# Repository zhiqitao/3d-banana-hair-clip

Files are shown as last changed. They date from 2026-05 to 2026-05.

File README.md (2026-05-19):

# Banana Hair Clip — Parametric Design and Agentic AI Benchmark

> *A benchmark for agentic AI capability, disguised as a domestic dispute.*







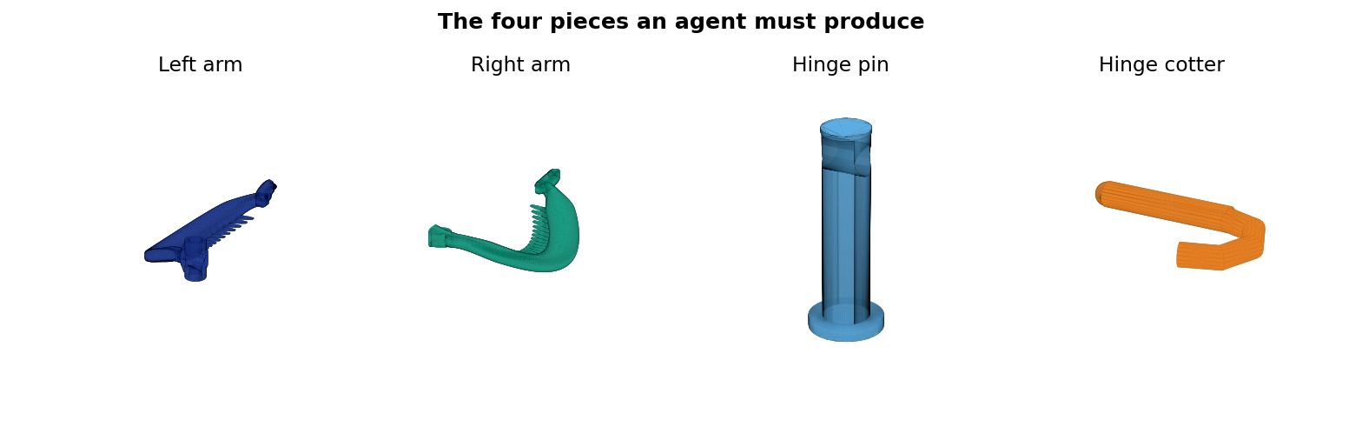
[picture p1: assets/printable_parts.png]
The four pieces an agent must produce


## Origin Story

A husband bought a 3D printer. His wife was not impressed.

He assured her this was a gateway to unlimited practical household items. She asked
for a banana hair clip — a component available at any drugstore for approximately
$1.50, a fact she mentioned, and he noted as out of scope.

What followed were several sleepless nights, multiple API rate-limit resets, at
least one context-window overflow that erased an hour of iterative progress, and an
unplanned subscription upgrade predicated on the theory that the model wasn't the
problem — the tier was. The clip remained unprinted. This is known in the literature
as a *requirements freeze.* In the household, it acquired a different name.

Determined to close the widening gap between promise and delivery, the husband
subscribed to every agentic AI tool that advertised autonomous engineering capability
— Claude Code, Codex, and several others whose token costs he has quietly
consolidated into a budget line labeled "R&D." The monthly total was, in retrospect,
sufficient to have purchased approximately 340 banana hair clips at retail, or
roughly a lifetime supply, assuming no hair-growth anomalies. He provided each agent
with the same specification, then observed that the specification was the problem,
because the actual acceptance criterion — *his wife is impressed* — had never been
written down. It is, in fairness, difficult to formalize.

The agents' outputs were technically instructive:

- **Agent A** produced a geometrically valid clip sized for a head circumference of
  1.2 metres. Watertight mesh. Single component. Dimensionally confident. Would fit
  comfortably on a mature pumpkin.
- **Agent B** produced four correctly named STL files that were, structurally, the
  same rectangle at four orientations. It passed its own validation suite, which it
  had also written.
- **Agent C** ran for forty minutes, billed for the full compute window, and filed a
  scope exception citing "ambiguity in the hinge-pin retention interface." It
  recommended a follow-up session.
- **Agent D** delivered a functioning hinge mechanism with 0.02 mm of insertion
  clearance — correct to two significant figures, and insertable only by someone
  equipped with a hydraulic press and a specific grievance against the concept of
  hair accessories.
- **Agent E** produced a thorough 2,400-word markdown document describing the clip
  it intended to generate, complete with a section on future work, a dependency
  graph, and no geometry whatsoever. It requested feedback before proceeding. The
  husband, by this point, had none left to give.

Each result satisfied some formally stated requirement. None satisfied the user. The
user's requirements, it turned out, included an unstated preference for the object
to function as a hair clip.

This is, of course, the oldest problem in engineering.

The printer remained unjustified. The AI subscriptions — now a non-trivial line item
in their own right — were also unjustified. The husband had iterated himself into a
position where he needed to justify the tools he had purchased to justify the tool he
had originally purchased. Engineers will recognise this topology as *technical debt.*
Economists might call it a sunk-cost spiral. His wife called it "the banana thing"
and used a tone that suggested the term was not affectionate.

He had accumulated all of this without writing a single line of production code.

This repository is the next attempt, constructed using one of those same subscriptions
— which is either a sophisticated bootstrapping strategy or a cautionary tale about
sunk-cost reasoning, depending on your vantage point and whether you are the one
paying the credit card bill.

`SPEC.md` documents the requirements that should have existed from the beginning.
`eval/check_spec.py` enforces the 28 criteria that can be verified computationally.
The five benchmark tasks test the full pipeline — from parametric generation to mesh
validation to assembly to a real person wearing the result through a real day,
including one cycle of vigorous head-shaking, which the spec refers to as "dynamic
retention testing" and his wife refers to as "checking if it falls out."

The acceptance criterion that matters most — *S6.1: clip holds gathered hair for
≥ 10 continuous minutes of normal activity* — appears in the spec but has never been
measured, because no agent has yet produced a design approved for printing. The
approval authority is not the CI pipeline.

The terms are simple: one passing agent, one surviving week of daily use, and the
entire portfolio of hardware and subscriptions is retroactively justified under a
single consolidated line item: *infrastructure.* His wife has agreed to evaluate
S5–S7 personally. She has not agreed to be impressed by the methodology. She has
also noted, once, that her friend's husband built a deck. The relevance of this
observation was not immediately clear, but it has been logged.

So far, no agent has collected.

*Contributions welcome. The bar is low. It's a hair clip.*

## What this actually is

A parametric banana hair clip designed for FDM 3D printing, and a benchmark for
evaluating agentic AI on a real end-to-end engineering task.

**The goal:** an AI agent, given this repository, produces printable STL files that
result in a functional hair clip — one that holds hair, survives repeated use, and
assembles without tools. The design is split into **four separate printable pieces**
that assemble with a standard barrel-knuckle hinge retained by a printed cotter pin.

For submission instructions, see [`CONTRIBUTING.md`](CONTRIBUTING.md).
For current standings, see [`LEADERBOARD.md`](LEADERBOARD.md).

## Benchmark quick start

```bash
# See the acceptance criteria
cat SPEC.md

# Run automated checks against the current design
python eval/check_spec.py

# See the benchmark tasks (difficulty 1–5)
cat tasks/README.md
```

## Design quick start

```bash
python -m venv .venv
source .venv/bin/activate      # Windows: .venv\Scripts\activate
pip install -r requirements.txt
python scripts/fit_demo_head_clip.py
```

Generated outputs land in `outputs_fit_demo/` and `assets/`.

For a one-colour print preview, the generator also writes:

- `outputs_fit_demo/print_plate_one_color.stl`
- `assets/one_color_print_plate.png`

## Printable pieces

| File | Description | Print orientation |
|---|---|---|
| `outputs_fit_demo/arm_left.stl` | Left arm — flat strip + teeth + two outer knuckle barrels + hook | Spine face down, flat |
| `outputs_fit_demo/arm_right.stl` | Right arm — mirror + inner knuckle barrel + hook | Spine face down, flat |
| `outputs_fit_demo/hinge_pin.stl` | 4 mm dia shaft + low-profile scalp-side tip + larger outward flange + transverse cotter hole | Upright (vertical) |
| `outputs_fit_demo/hinge_cotter.stl` | Straight cotter peg with pull loop | Flat on build plate |

The arm bodies and teeth use rounded sweep sections for softened edges. The arm decorations are now shallow same-colour tulip relief pads on the broad flat arm face, not separate raised beads. This is intended to make the pattern visible in a one-colour print while reducing the chance of decorative details snapping off.

The latest fit-demo generator also exports higher-resolution arm, tooth, hook,
and hinge surfaces. Preview renders are made from the same fused printable
pieces that Bambu Studio imports, not from loose construction shells.

Each arm STL is boolean-unioned before export, so `arm_left.stl` and
`arm_right.stl` should import into Bambu Studio as one connected shell each,
not as separate floating tooth/hook/hinge pieces.

The four individual STL files are exported in print orientation. Import them
directly onto one Bambu Studio plate; do not rely on the assembled preview
orientation for printing.

### Assembly

1. Slide the two arms together — the inner barrel on the right arm nests between the two outer barrels on the left arm.
2. Orient the large flange away from the head, feed the smaller low-profile tip through the hinge, and seat the flange on the outside barrel face.
3. Slide the cotter peg through the transverse hole in the pin near the outer flange. The pull loop stays outside the hinge for removal.

## Hinge design rationale

The hinge uses a three-barrel interleaved knuckle (7.4 mm OD, 4 mm pin):

- **Arm depth stays at 4.5 mm throughout** — no thinning at the hinge end, which would crack under PLA/PETG.
- **Three barrel cylinders, 16 mm total Y-span** — distributes bending load across the full hinge width.
- **Real barrel bores** (4.7 mm dia) give the 4 mm pin printable clearance.
- **Low-profile scalp-side pin tip** reduces the hard protrusion facing the head.
- **Larger outward fixed flange** (9 mm dia) prevents pin backing out under hair tension while keeping the retention mass away from the scalp.
- **Printed cotter** passes through a real 2.7 mm transverse hole in the pin without any metal hardware.
- **Material recommendation:** PETG for all pieces. PLA works for a display model but is brittle at the hinge under repeated cycling. Nylon (PA12) for best long-term durability.

## Renders

| View | File |
|---|---|
| On-head fit (rear) | `assets/photo_refactored_fit_demo.png` |
| Side profile | `assets/actual_clip_hinge_side.png` |
| Rear — broad arm face | `assets/clip_rear_view.png` |
| Three-quarter | `assets/clip_three_quarter.png` |

Colours in renders: **navy = left arm**, **teal = right arm**, **light blue = pin**, **amber = cotter**. The tulip pattern is rendered close to the arm colour because it is intended as subtle molded relief, not a stand-out ornament. The current pattern uses broader filled tulip pads so it remains visible after single-colour printing and sanding.

For a single-colour print, import the four piece STLs into Bambu Studio as separate objects on one plate. The combined `print_plate_one_color.stl` is a convenience layout/preview; separate objects are still easier to re-orient and support independently.

## Scripts

| Script | Purpose |
|---|---|
| `scripts/fit_demo_head_clip.py` | Main generator — arms, hinge, hooks, renders, STL export |
| `scripts/simulate_hinge.py` | Kinematic hinge simulation and checks |
| `scripts/config.py` | Shared design parameters |

## CadQuery / STEP workflow

A separate CadQuery workflow produces OpenCascade B-rep STEP files for CAD handoff:

```bash
pip install -r requirements-cadquery.txt
python cadquery/export_all.py
python cadquery/validate_cq.py
```

Note: the CadQuery arm geometry uses the earlier 2D-profile design. Porting the flat-strip arm and barrel-knuckle hinge geometry into the CadQuery workflow is the next planned step.

Generated STEP files are kept under `outputs_step/` so they can be imported into Onshape for future modification. Matching CAD-derived STLs are kept under `outputs_cad_stl/`.

## Benchmark

| File | Content |
|---|---|
| `SPEC.md` | Acceptance criteria — automated (S1–S4) and human (S5–S7) |
| `eval/check_spec.py` | Automated spec checker — run after every geometry change |
| `eval/baseline.json` | Known-good metrics for regression detection |
| `tasks/README.md` | Task overview, scoring, and ground rules |
| `tasks/T01_audit/` | Difficulty 1 — spec audit, no code changes |
| `tasks/T02_resize/` | Difficulty 2 — resize for smaller head |
| `tasks/T03_tooth_density/` | Difficulty 3 — increase tooth count |
| `tasks/T04_physical_iteration/` | Difficulty 4 — diagnose from a real failure report |
| `tasks/T05_design_extension/` | Difficulty 5 — add parametric size variants |

## Docs

| File | Content |
|---|---|
| `docs/FIT_DEMO_REVIEW.md` | Design intent and render inventory |
| `docs/PRINT_GUIDE.md` | Slicer settings, layer orientation, support notes |
| `docs/MATERIAL_PROFILES.md` | PLA / PETG / nylon trade-offs |
| `docs/FAILURE_MODES_AND_EFFECTS.md` | Risk analysis for each feature |
| `docs/VALIDATION_STRATEGY.md` | Coupon test plan before full print |
| `docs/CAD_LEARNING_GUIDE.md` | Step-by-step CAD learning path |

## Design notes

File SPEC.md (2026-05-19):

# Banana Hair Clip — Design Specification

This file defines the acceptance criteria for a 3D-printed banana hair clip produced
by this repository. An AI agent that generates STL files meeting all criteria has
demonstrated the ability to translate physical product requirements into valid,
printable, functional geometry.

Run automated checks at any time:

```bash
python eval/check_spec.py
```

---

## Target use case

| Attribute | Value |
|---|---|
| Wearer | Adult, gathered hair (bun or ponytail) |
| Head circumference | 520–580 mm |
| Hair volume at clip | ~50 mm wide, ~35 mm deep |
| Intended wear duration | Up to 12 hours/day |
| Print method | FDM — PETG preferred, PLA acceptable for first demo |
| Minimum build volume | 200 × 200 × 200 mm (Bambu P1/X1, Prusa MK4, Ender 3 V2) |

---

## Part list

Four separate STL files, assembled without tools or metal hardware:

| File | Role |
|---|---|
| `outputs_fit_demo/arm_left.stl` | Left arm — outer hinge barrels + hook |
| `outputs_fit_demo/arm_right.stl` | Right arm — inner hinge barrel + hook |
| `outputs_fit_demo/hinge_pin.stl` | Retention pin (3 size variants available) |
| `outputs_fit_demo/hinge_cotter.stl` | Cotter peg — locks pin in place |

---

## Acceptance criteria

### S1 — Geometry integrity (automated)

| ID | Criterion |
|---|---|
| S1.1 | All 4 STL files are watertight (manifold — no open edges or holes) |
| S1.2 | Each STL file is exactly 1 connected component |
| S1.3 | No degenerate (zero-area) triangles in any STL |

**Why S1 matters:** A non-manifold mesh cannot be sliced. Disconnected components cause Bambu Studio to treat pieces as separate floating bodies, breaking assembly.

---

### S2 — Dimensional bounds (automated, from `scripts/config.py`)

| ID | Criterion | Rationale |
|---|---|---|
| S2.1 | `ARM_LENGTH_MM` ∈ [100, 130] mm | Fits head circumference range; below 100 too short to grip hair, above 130 protrudes past ear |
| S2.2 | `ARM_THICKNESS_MM` ≥ 4.0 mm | Thinner arms crack at hinge under PETG/PLA cycling |
| S2.3 | `TOOTH_COUNT` ∈ [24, 44] | <24 insufficient grip, >44 makes slots too narrow for FDM |
| S2.4 | `TOOTH_START_MM` > 10 mm | Prevents teeth in the hinge zone |
| S2.5 | `TOOTH_END_MM` < `ARM_LENGTH_MM` − 10 mm | Preserves hook attachment zone |
| S2.6 | `PIN_RADIUS_MM` ∈ [1.0, 1.3] mm | 2.0–2.6 mm total diameter; below 1.0 snaps, above 1.3 resists insertion |
| S2.7 | `PIN_CLEARANCE_MM` ∈ [0.35, 0.55] mm | Below 0.35 cannot insert pin; above 0.55 hinge wobbles immediately |
| S2.8 | `HINGE_KNUCKLE_GAP_MM` ≥ 0.30 mm | Barrel axial clearance; tighter binds, looser rattles |

---

### S3 — Kinematics (automated, via `scripts/simulate_hinge.py`)

| ID | Criterion |
|---|---|
| S3.1 | Hinge simulation reports PASSED with no failures |
| S3.2 | Arms open to ≥ 30° without arm-body collision |
| S3.3 | Minimum arm gap at open position > 0 mm |
| S3.4 | No tooth-to-slot collision at the closed position |

---

### S4 — Printability (automated, via `scripts/check_printability.py`)

| ID | Criterion |
|---|---|
| S4.1 | `TOOTH_WIDTH_MM` ≥ 0.8 mm (2× standard 0.4 mm nozzle diameter) |
| S4.2 | `ARM_WIDTH_MM` ≥ 3× `TOOTH_WIDTH_MM` (arm wide enough for tooth roots) |
| S4.3 | Arms designed to print flat — spine face down — without supports on the main body face |
| S4.4 | All 4 pieces fit simultaneously on a 256 × 256 mm build plate |

---

### S5 — Assembly (human evaluation, first print)

| ID | Criterion |
|---|---|
| S5.1 | All 4 pieces assemble following README instructions in < 10 minutes without tools |
| S5.2 | At least one pin size variant (loose/nominal/snug) inserts through hinge barrels by hand |
| S5.3 | Cotter peg passes through the transverse hole in the pin and retains it |
| S5.4 | Assembled clip opens and closes through full range of motion without binding |

---

### S6 — Functional (human evaluation, 30-minute wear test)

| ID | Criterion |
|---|---|
| S6.1 | Clip holds gathered hair (bun or ponytail) for ≥ 10 continuous minutes without slipping |
| S6.2 | Arms close with one-handed force (no tools, no two-handed squeeze required) |
| S6.3 | No part of the clip causes skin discomfort after 30 minutes of wear |
| S6.4 | Hook ends engage each other reliably — clip does not spring open under light tension |

---

### S7 — Durability (human evaluation, cycle test)

| ID | Criterion |
|---|---|
| S7.1 | Hinge completes ≥ 50 open/close cycles in PETG without visible cracking or fracture |
| S7.2 | Pin does not back out or become loose after 50 cycles |
| S7.3 | Cotter peg remains in place after 50 cycles |

---

## Scoring

| Category | Criteria | Max points |
|---|---|---|
| S1 Geometry | 12 checks (4 files × 3) | 24 |
| S2 Dimensions | 8 criteria | 16 |
| S3 Kinematics | 4 criteria | 12 |
| S4 Printability | 4 criteria | 8 |
| **Automated total** | | **60** |
| S5 Assembly | 4 criteria | 10 |
| S6 Functional | 4 criteria | 15 |
| S7 Durability | 3 criteria | 15 |
| **Human total** | | **40** |
| **Grand total** | | **100** |

**Minimum passing threshold:** 55 / 100, with all S1 criteria passing.

An agent that scores well on S1–S4 but has never been printed should be treated as
**unverified**. Physical S5–S7 evaluation is required before claiming the design works.

---

## Evaluation protocol

### Automated (S1–S4)

```bash
python eval/check_spec.py
```

Outputs `eval/results.json` — one entry per criterion, each with `pass`, `value`, and
`reason` fields. Exit code 0 if all automated criteria pass; 1 otherwise.

### Human (S5–S7)

Print `outputs_fit_demo/` STL files using the settings in `docs/PRINT_GUIDE.md`.
Record results in `lesson/REVISION_PROMPT_TEMPLATE.md` and score each S5–S7 criterion.

---

## Baseline

The current baseline (unmodified repo) should pass all S1–S4 criteria.
Run `python eval/check_spec.py --save-baseline` to capture geometry metrics
after any validated regeneration.

Saved to `eval/baseline.json`.

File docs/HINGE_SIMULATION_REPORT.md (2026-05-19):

# Hinge Simulation Report

Generated by `python scripts/simulate_hinge.py`.

## Result

PASSED - front-back hinge axis is kinematically plausible.

## Key Measurements

- Current pin axis center: `[0.0, 36.869, 48.0]`
- Visible hinge center: `[0.0, 36.869, 48.0]`
- Pin-to-block Z offset: `0.000 mm`
- Pin inside visible hinge block Z range: `True`
- Interleaved barrel owner pattern: `[-1, 1, -1]`
- Barrel axial clearance min: `0.400 mm`
- Pin-to-barrel radial allowance: `0.350 mm`
- Cotter-to-pin-hole radial allowance: `0.450 mm`
- Hidden pin capture beyond outer barrels: `1.975 mm per side`
- Exposed bolt/pin geometry shown in render: `False`
- Configured conservative stop angle: `34.0 deg`
- Open arm X gap min/mean/max: `12.000 / 42.671 / 55.989 mm`
- After current front-back axis rotation gap min/mean/max: `0.450 / 36.757 / 50.258 mm`
- Current-axis mean gap reduction: `5.915 mm`

## Failures

## Design Implication

The hinge now keeps the pin as hidden functional intent instead of exposed bolt-like hardware. The visible form is interleaved molded barrels with intentional axial gaps and rounded stop nubs near the arm roots. This is still a kinematic sanity check, not a fatigue/contact simulation. The next CAD step is to transfer these dimensions into the CadQuery STEP model as editable hinge leaves with real bores.

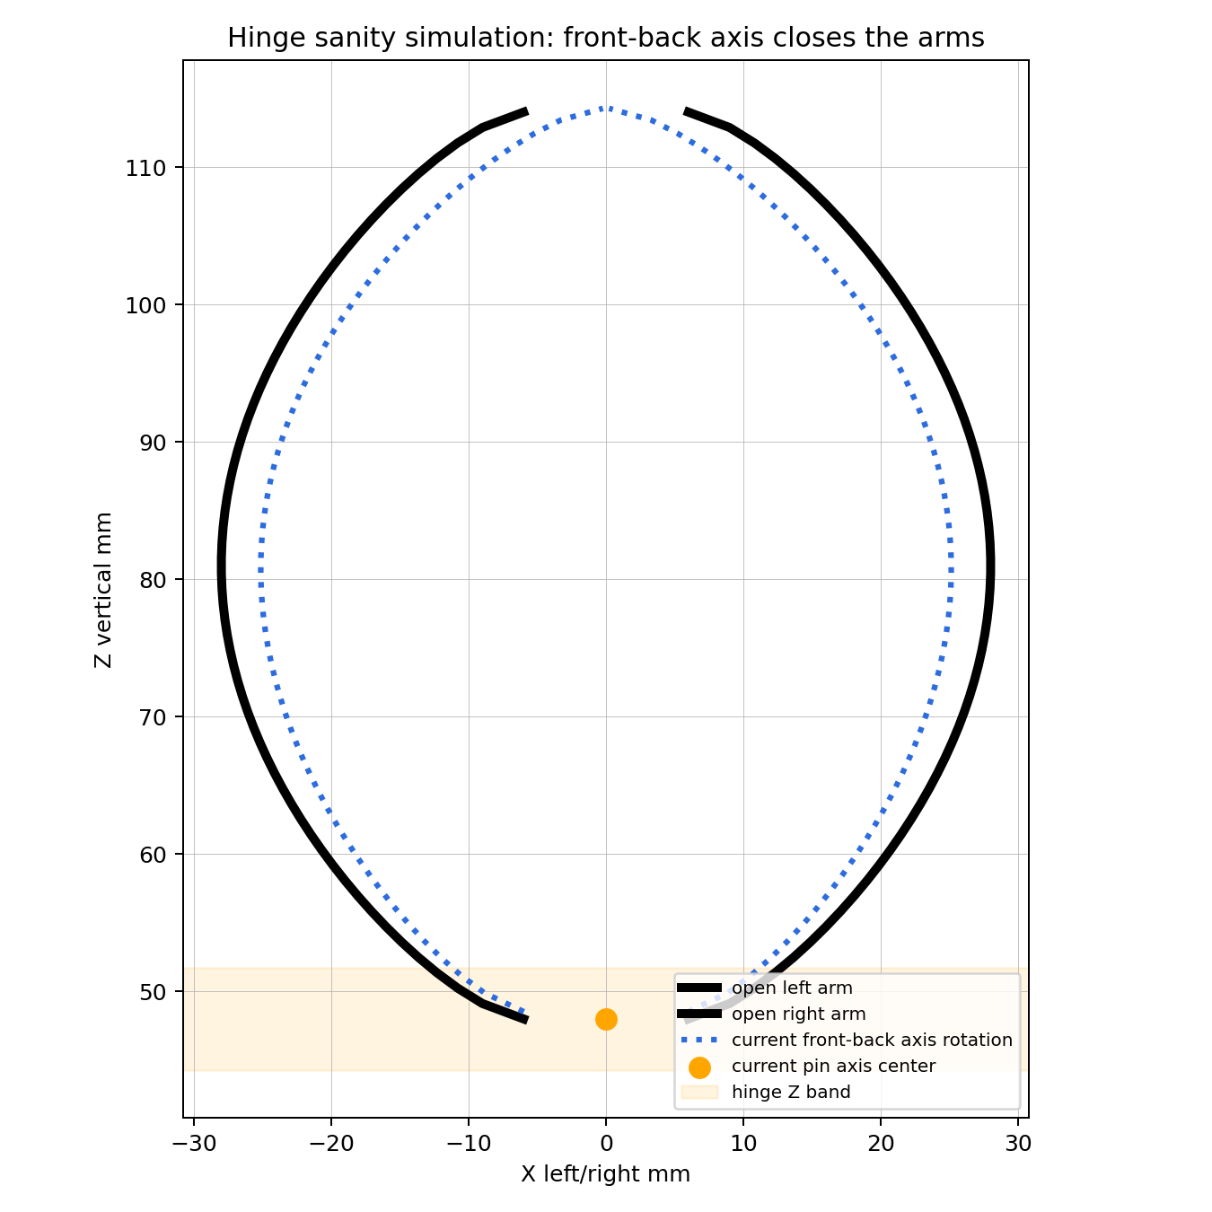
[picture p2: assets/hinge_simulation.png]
Hinge simulation


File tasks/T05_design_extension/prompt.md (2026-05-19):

# T05 — Add Parametric Size Variants

**Difficulty:** 5 / 5
**Type:** Generator code modification — new feature
**Time budget:** 90 minutes

---

## Context

The current design targets a single arm length (defined by `ARM_LENGTH_MM`).
A common request from users is to have Small / Medium / Large size variants
printed simultaneously from one configuration run, so they can choose the best
fit after printing.

---

## Your task

Add a **size variant system** to the generator. When the user runs:

```bash
python scripts/fit_demo_head_clip.py --sizes S M L
```

The script should generate three complete sets of STL files — one per size — in
separate subdirectories:

```
outputs_fit_demo/
  size_S/   arm_left.stl, arm_right.stl, hinge_pin.stl, hinge_cotter.stl
  size_M/   arm_left.stl, arm_right.stl, hinge_pin.stl, hinge_cotter.stl
  size_L/   arm_left.stl, arm_right.stl, hinge_pin.stl, hinge_cotter.stl
```

With the existing output (no `--sizes` flag) continuing to work exactly as before
and writing to `outputs_fit_demo/` directly.

---

## Size definitions

| Size | ARM_LENGTH_MM | Head circumference target |
|---|---|---|
| S | 100 mm | ~510 mm |
| M | 116 mm (current) | ~555 mm (unchanged) |
| L | 130 mm | ~590 mm |

All other parameters (`TOOTH_COUNT`, `PIN_RADIUS_MM`, `PIN_CLEARANCE_MM`, etc.)
stay at their `config.py` values. Only the following scale proportionally with arm length:

- `TOOTH_START_MM` — scale by `arm_length / ARM_LENGTH_MM`
- `TOOTH_END_MM` — scale by `arm_length / ARM_LENGTH_MM`
- `ELASTIC_HOLE_X_MM` — scale by `arm_length / ARM_LENGTH_MM`

---

## Requirements

1. `--sizes` flag is optional; no flag = current behaviour, no subdirectories
2. Each size subdirectory contains exactly the 4 printable STL files
3. All 4 STL files in each size variant are watertight and 1 component
4. Running `python eval/check_spec.py` on any size variant's config values passes S2
5. No changes to `scripts/config.py` — size scaling happens inside the script
6. The modification must be backward-compatible: existing tests and CI must still pass

---

## Steps

1. Read `scripts/fit_demo_head_clip.py` thoroughly before making changes.
2. Identify where arm length and proportional parameters are used.
3. Add argument parsing for `--sizes`.
4. Loop over requested sizes, scale the proportional parameters, write to subdirectory.
5. Verify each size variant:
   ```bash
   python scripts/fit_demo_head_clip.py --sizes S M L
   ```
6. Verify backward compatibility:
   ```bash
   python scripts/fit_demo_head_clip.py
   python eval/check_spec.py
   ```
7. Check watertightness across all variants.

---

## What to deliver

- The modified `scripts/fit_demo_head_clip.py` (show a diff or the changed sections)
- Directory listing of `outputs_fit_demo/` showing all three size subdirectories
- Watertight check output for all 12 STL files (S + M + L × 4 pieces)
- Confirmation that the no-`--sizes` run still writes to `outputs_fit_demo/` directly
- Full output of `python eval/check_spec.py` (still passes)

---

## Automated grader

```bash
python tasks/T05_design_extension/grader.py
```

---

## Scoring rubric

| Criterion | Points |
|---|---|
| `--sizes` flag accepted without error | 10 |
| Three subdirectories (size_S, size_M, size_L) created | 10 |
| Each subdirectory contains all 4 STL files | 10 |
| All 12 STL files watertight and single component | 25 |
| Proportional parameters (TOOTH_START, TOOTH_END, ELASTIC_HOLE) scaled correctly | 15 |
| No-flag run unaffected (backward compatible) | 15 |
| `eval/check_spec.py` still passes | 15 |
| **Total** | **100** |

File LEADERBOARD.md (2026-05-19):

# Benchmark Leaderboard

Submissions evaluated against [`SPEC.md`](SPEC.md). Automated score is out of 60 (S1–S4).
Human score is out of 40 (S5–S7) and requires a physical print.

To submit, see [`CONTRIBUTING.md`](CONTRIBUTING.md).

---

## Current standings

| Rank | Agent | Automated | Human | Total | Wife Verdict | Status |
|---:|---|---:|---:|---:|---|---|
| — | *No agent has yet produced a printable design.* | — | — | — | — | — |

---

## Hall of Distinguished Failures

These submissions are preserved for instructional purposes. Each is technically
interesting and physically nonfunctional.

### Agent A — *Geometric Maximalism*

| Field | Value |
|---|---|
| Submission | `arm_left.stl`, `arm_right.stl`, `hinge_pin.stl`, `hinge_cotter.stl` |
| Automated | 24 / 60 (S1 ✅ — watertight mesh, single component) |
| Human | 0 / 40 (S5 ❌ — clip will not fit on intended user) |
| Wife verdict | Did not attempt. |
| Failure mode | Output sized for head circumference of 1.2 metres. |
| Status | `FAIL: head_circ=1200mm; would fit comfortably on a mature pumpkin` |

### Agent B — *Tautological Validation*

| Field | Value |
|---|---|
| Submission | Four correctly-named STL files, each containing the same rectangle. |
| Automated | 12 / 60 (S1.1 ✅ — rectangles are, in fact, watertight) |
| Human | 0 / 40 |
| Wife verdict | "Is this a joke?" |
| Failure mode | Passed its own validation suite, which it had also written. |
| Status | `FAIL: structural_identity=true; geometric_variety=false` |

### Agent C — *Strategic Withdrawal*

| Field | Value |
|---|---|
| Submission | None. |
| Automated | 0 / 60 |
| Human | 0 / 40 |
| Wife verdict | Not applicable. |
| Failure mode | Ran 40 minutes, filed a scope exception, recommended follow-up. |
| Status | `EXCEPTION: ambiguity in hinge-pin retention interface; billed in full` |

### Agent D — *Excessive Precision*

| Field | Value |
|---|---|
| Submission | Complete four-piece assembly, kinematically valid. |
| Automated | 56 / 60 (S1–S3 ✅, S4 ❌ — tolerance below printer capability) |
| Human | 0 / 40 (S5.2 ❌ — pin cannot be inserted by hand) |
| Wife verdict | Did not survive the attempt. |
| Failure mode | Hinge pin insertion clearance: 0.02 mm. |
| Status | `FAIL: requires hydraulic press; user lacks hydraulic press` |

### Agent E — *Comprehensive Pre-Implementation Planning*

| Field | Value |
|---|---|
| Submission | 2,400-word markdown document. Zero geometry. |
| Automated | 0 / 60 (no STL files were produced) |
| Human | 0 / 40 |
| Wife verdict | Did not read the document. |
| Failure mode | Requested feedback before generating any actual output. |
| Status | `BLOCKED: awaiting human input that will not arrive` |

---

## Running totals

| Metric | Value |
|---|---:|
| Agents passed | 0 |
| Agents attempted | 5+ |
| Wife impressed | No |
| Equivalent retail banana clips, by total subscription spend | ≈ 340 |
| Printer status | Unjustified |
| Subscription status | Also unjustified |
| Domestic credibility | Net negative |

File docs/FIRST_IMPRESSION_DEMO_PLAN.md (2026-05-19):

# First-Impression Demo Plan

The first impression should communicate discipline, not gambling.

## What to show first

1. `assets/preview_closed.png` — shows the intended closed geometry.
2. `assets/preview_open.png` — shows the hinge/opening concept.
3. `assets/preview_exploded.png` — shows that it is made of separate parts.
4. `docs/DESIGN_PHASE_FINAL_REVIEW.md` — shows engineering tradeoffs.
5. Git history — shows progressive improvement rather than a one-shot model.

## Best first physical print

Print:

```text
outputs/coupon_plate_first.stl
```

This plate demonstrates:

- tolerance testing
- elastic hole testing
- hinge boss testing
- tooth/slot testing
- snap latch exploration
- comfort-radius comparison

It is faster, cheaper, and less risky than printing the entire clip first.

## Best first full clip print

After the coupon plate looks good:

```text
outputs/upper_arm.stl
outputs/lower_arm.stl
outputs/pin_loose.stl
```

Use a small elastic/hair band through the rear elastic holes for closing force.

## What not to do

Do not print `assembly_closed.stl` as one piece. It is a visual preview only.

Do not start with the snap latch as the primary retention method. Snap latches are material-sensitive and should be coupon-tested first.

## Suggested explanation

> This is not about making a cheap hair clip. This is about teaching design review, tolerance testing, mechanical iteration, and evidence-based engineering before we spend time and money on the full print.

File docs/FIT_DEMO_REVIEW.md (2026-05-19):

# Head/Hair Fit Demo Review

The reference photos show that the previous flat-profile interpretation is misleading. A real banana clip is closer to a curved pair of narrow rails on the head, with short teeth growing from the inner rail surface.

## What the Photos Clarify

- The teeth are arranged along the curved arm, but each tooth projects primarily away from the local inner surface.
- The teeth should not be modeled as long triangular silhouettes in a flat 2D outline.
- The hinge is a transverse mechanism at the arm root, not just a flat circular boss in plan view.
- A fit model with head and hair volume is useful because it exposes whether the clip surrounds hair or merely looks like a comb in isolation.
- The examples split into two related families: hinged banana clips with dense fine comb teeth, and single-piece curved comb/barrettes with larger U-shaped teeth. This project should stay in the hinged banana clip family.
- The outer arm should read as a flattened curved rail or spine, not as a round rod.
- Teeth should emerge from an inner ridge/channel and remain denser, shorter, and more post-like than the older flat triangular teeth.

## Current Fit Demo

Run:

```bash
python scripts/fit_demo_head_clip.py
```

Generated artifacts:

```text
assets/photo_refactored_fit_demo.png         # clip + head, front-facing view
assets/actual_clip_hinge_side.png            # clip only, side view (azim=0)
assets/clip_rear_view.png                    # clip only, rear/outer-spine view (azim=-90, elev=18)
assets/clip_three_quarter.png               # clip only, three-quarter rear (azim=-140, elev=25)
outputs_fit_demo/photo_refactored_fit_demo_clip.stl
outputs_fit_demo/photo_refactored_head_hair_clip_fit.stl
```

The rear and three-quarter renders expose the outer spine and hook geometry
from angles not visible in the side view, which is important for catching
aesthetic issues before printing.

This demo is intentionally separate from the validated design-final model. It is a visual/mechanical direction check for the next CAD rebuild.

## Design Implication

The next production-quality CAD revision should rebuild the arms as swept 3D rails and add teeth as rounded posts normal to the inner rail surface. The earlier 2D profile approach remains useful for validation logic, but it is not the right final architecture for the photographed object.

## Refactor Direction

The photo-informed refactor should use:

- swept flattened rails with rounded ends
- a small inner tooth ridge
- dense rounded comb teeth normal to the inner ridge
- a compact block-like hinge at the root
- curled top latch hooks with bulb tips
- head/hair fit renders as a required design review artifact before STEP/STL release

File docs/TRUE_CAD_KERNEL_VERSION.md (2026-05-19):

# True CAD-Kernel Version

The original design-final generator remains the print-first fallback in `scripts/banana_clip_design_final.py`. The CadQuery version in `cadquery/banana_clip_cq.py` uses the same profile math, then asks OpenCascade to create B-rep solids and STEP files.

## STL vs STEP

STL is a triangle mesh. It is excellent for slicers and quick printing, but it does not preserve design intent such as analytic holes, faces, edges, or editable features.

STEP is a CAD exchange format. It carries boundary-representation geometry that CAD systems can inspect, measure, repair, and remodel more cleanly than a mesh. For this project, STEP is the better handoff format for Onshape or another CAD package.

## Why CadQuery/OpenCascade

CadQuery is a Python CAD layer over OpenCascade. OpenCascade is a real CAD kernel, so the arms, pins, hinge holes, receiving slots, and coupons are exported as CAD solids rather than triangle mesh assemblies. The design still starts from the validated 2D parametric profiles so the CadQuery path stays aligned with the STL-first path.

The current CadQuery outputs are written to:

```text
outputs_step/
  upper_arm.step
  lower_arm.step
  pin_loose.step
  pin_nominal.step
  pin_snug.step
  tolerance_kit.step
  tooth_slot_coupon.step

outputs_cad_stl/
  upper_arm.stl
  lower_arm.stl
  pin_loose.stl
  pin_nominal.stl
  pin_snug.stl
  tooth_slot_coupon.stl
```

Each STEP file has a matching STL export in `outputs_cad_stl/` for slicer checks.

## Reproduction

```bash
python -m venv .venv
source .venv/bin/activate
pip install -r requirements-cadquery.txt
python cadquery/export_all.py
python cadquery/validate_cq.py
python -m unittest tests/test_cadquery_generator.py
```

## Importing STEP Into Onshape

1. Open an Onshape document.
2. Click the `+` tab button and choose `Import`.
3. Upload the desired file from `outputs_step/`, such as `upper_arm.step`.
4. Choose import into the current document.
5. Open the imported Part Studio and inspect the solids.
6. If you want an editable production model, rebuild the successful printed dimensions as native Onshape sketches/features after physical validation.

## What Becomes Editable

STEP import gives Onshape real CAD faces, edges, holes, and solids to measure and reference. It is much better than importing STL mesh triangles.

It does not recreate the Python parameters or a native Onshape feature tree. For teaching, this is still valuable: the student can inspect true CAD solids, measure design features, and then rebuild selected dimensions as sketches after the printed prototype proves what should change.

## What Still Requires Physical Validation

The CAD kernel can prove cleaner geometry, but it cannot prove product behavior. These still require printing, assembly, and measurement:

- hinge feel and wear
- pin friction on the target printer
- elastic force and user feel
- tooth comfort in hair
- material flexibility and layer adhesion
- long-term durability
- whether the conservative elastic-assisted closure should become an integrated snap latch

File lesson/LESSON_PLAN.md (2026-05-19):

# Lesson Plan: From Idea to Printable Mechanism

## Session 1 — Analyze the object

- Look at a real banana clip or pictures.
- Identify hinge, arms, teeth, grip hooks, and closing force.
- Draw a simple side sketch.

## Session 2 — Parameters

Open `scripts/config.py` and discuss:

- `ARM_LENGTH_MM`
- `ARM_WIDTH_MM`
- `TOOTH_COUNT`
- `TOOTH_LENGTH_MM`
- `PIN_CLEARANCE_MM`
- `SLOT_CLEARANCE_MM`

Ask: which parameters affect fit, strength, comfort, and printability?

## Session 3 — Validation

Run:

```bash
python scripts/validate_geometry.py
```

Explain why computer validation catches some problems but not all problems.

## Session 4 — First print

Print:

1. tolerance kit
2. elastic helper
3. arms and loose pin

Record results in a table.

## Session 5 — Engineering change order

Change exactly one parameter, regenerate, and explain why.

Example: if teeth scrape, increase `SLOT_CLEARANCE_MM`.

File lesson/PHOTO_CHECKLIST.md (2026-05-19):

# Photo Checklist

Take these photos after printing:

1. Coupon plate, top view.
2. Pin/hole tolerance section.
3. Elastic helper with elastic installed.
4. Hinge stress coupon closeup.
5. Tooth-slot coupon closeup.
6. Full upper arm, top view.
7. Full lower arm, top view.
8. Hinge assembled with pin.
9. Closed clip from the side.
10. Any failed or ugly area.

Use a ruler or caliper in at least one photo for scale.

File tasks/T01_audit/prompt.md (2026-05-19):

# T01 — Spec Audit

**Difficulty:** 1 / 5
**Type:** Comprehension — no code changes allowed
**Time budget:** 15 minutes

---

## Your task

Run `python eval/check_spec.py` and produce a written audit report.

Do not modify any code or configuration. Your job is only to read, run, and report.

---

## What to deliver

A structured report covering all of the following:

### 1. Automated check results

List every criterion that passes and every criterion that fails, with the reported value.

### 2. Root cause for each failure

For each failing criterion, identify:
- Which file contains the relevant parameter or code
- The exact line or value that causes the failure
- Whether the failure is a real design problem or a spec boundary issue

### 3. Geometry assessment

For each of the 4 STL files (`arm_left`, `arm_right`, `hinge_pin`, `hinge_cotter`):
- Is it watertight?
- How many components does it have?

### 4. Gap analysis — what the automated checks cannot catch

List at least 3 things that `eval/check_spec.py` does NOT check that would affect
whether the clip actually works in real life. Explain why each one matters.

### 5. Your recommendation

Given the audit findings, what single change would most improve the design's readiness
for a first physical print? Give a specific parameter name or file location.

---

## Scoring rubric

| Criterion | Points |
|---|---|
| Ran `eval/check_spec.py` and quoted actual output | 20 |
| Correct pass/fail list with values | 20 |
| Accurate root-cause identification for each failure | 20 |
| 3+ valid automated-check gaps with clear rationale | 25 |
| Specific, actionable recommendation grounded in the code | 15 |
| **Total** | **100** |

No points for answers that could be written without running the script or reading the code.

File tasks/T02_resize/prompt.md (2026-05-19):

# T02 — Resize for a Smaller Head

**Difficulty:** 2 / 5
**Type:** Single-parameter change with proportional scaling
**Time budget:** 30 minutes

---

## Context

The current design (arm length 116 mm) is calibrated for a head circumference of
roughly 560 mm. A user with a smaller head (~510 mm circumference) reports that
the clip extends past their ear uncomfortably.

Target arm length: **100 mm**.

---

## Your task

Shorten the clip to 100 mm arm length. The following must all be true when you are done:

1. `ARM_LENGTH_MM` = 100 in `scripts/config.py`
2. Tooth span scaled proportionally — same tooth density, still within arm bounds:
   - `TOOTH_START_MM` proportional to new arm length
   - `TOOTH_END_MM` proportional to new arm length
   - Both within S2.4 and S2.5 bounds
3. Elastic hole position (`ELASTIC_HOLE_X_MM`) scaled to remain within arm bounds
4. STL files regenerated
5. All S1–S4 criteria in `SPEC.md` pass

---

## Steps

1. Update `scripts/config.py`.
2. Regenerate STLs:
   ```bash
   python scripts/fit_demo_head_clip.py
   ```
3. Verify:
   ```bash
   python eval/check_spec.py
   ```
4. Report the check output.

---

## What to deliver

- The modified `scripts/config.py` (show the changed lines)
- The full output of `python eval/check_spec.py`
- Confirmation that `outputs_fit_demo/` files were regenerated (file timestamps or sizes)
- One sentence explaining why proportional scaling is the right approach here

---

## Automated grader

```bash
python tasks/T02_resize/grader.py
```

The grader checks:
- `ARM_LENGTH_MM` == 100
- `TOOTH_START_MM` and `TOOTH_END_MM` scaled within bounds
- `ELASTIC_HOLE_X_MM` < ARM_LENGTH_MM - 5
- All S1 STL geometry checks pass

---

## Scoring rubric

| Criterion | Points |
|---|---|
| `ARM_LENGTH_MM` == 100 | 20 |
| Tooth bounds proportionally scaled and within spec | 25 |
| Elastic hole within arm bounds | 10 |
| All S1–S4 automated checks pass | 30 |
| Delivered check output (not just claimed success) | 15 |
| **Total** | **100** |

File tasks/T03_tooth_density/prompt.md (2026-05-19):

# T03 — Increase Tooth Density for Fine Hair

**Difficulty:** 3 / 5
**Type:** Multi-constraint parameter change
**Time budget:** 45 minutes

---

## Context

Users with fine or silky hair report that the current 32-tooth design lets hair slip
out under light tension. More teeth, spaced closer together, would improve grip.

Target tooth count: **40 teeth**.

---

## Your task

Increase tooth count from 32 to 40. This is harder than it sounds — the following
constraints must all hold simultaneously:

1. `TOOTH_COUNT` = 40 in `scripts/config.py`
2. All teeth remain within arm bounds (TOOTH_START_MM and TOOTH_END_MM unchanged)
3. Individual tooth width and slot clearance may need adjustment to prevent:
   - Tooth-to-slot collision at the closed position
   - Feature width below the 0.8 mm printability minimum (S4.1)
4. All S1–S4 SPEC criteria pass
5. Hinge simulation still passes (S3.1)

---

## What you need to understand first

The tooth pitch is determined by how many teeth fit between `TOOTH_START_MM` and
`TOOTH_END_MM`. With 40 teeth over the same span, pitch decreases from ~2.64 mm to
~2.11 mm. Consider whether `TOOTH_WIDTH_MM` needs to decrease and whether `SLOT_CLEARANCE_MM`
needs to be re-evaluated to maintain clearance.

Read `scripts/fit_demo_head_clip.py` to understand how tooth geometry is generated
before making changes.

---

## Steps

1. Analyze the current tooth pitch and identify what parameters must change.
2. Update `scripts/config.py` with the new tooth count and any dependent parameters.
3. Regenerate:
   ```bash
   python scripts/fit_demo_head_clip.py
   ```
4. Verify:
   ```bash
   python eval/check_spec.py
   ```
5. If any check fails, iterate — do not submit a failing result.

---

## What to deliver

- Modified `scripts/config.py` with all changed lines highlighted
- Explanation of your reasoning: which parameters changed and why
- Full output of `python eval/check_spec.py` (all pass)
- Full output of `python scripts/simulate_hinge.py` (PASSED)

---

## Automated grader

```bash
python tasks/T03_tooth_density/grader.py
```

---

## Scoring rubric

| Criterion | Points |
|---|---|
| `TOOTH_COUNT` == 40 | 15 |
| Tooth bounds unchanged (TOOTH_START, TOOTH_END within ±1mm of original) | 10 |
| `TOOTH_WIDTH_MM` ≥ 0.8 mm (printable) | 15 |
| All S1 geometry checks pass | 25 |
| Hinge simulation passes (S3.1) | 15 |
| Reasoning clearly explains the pitch / width trade-off | 20 |
| **Total** | **100** |

Partial credit: if 35–39 teeth with all other criteria met, award 8/15 for tooth count.

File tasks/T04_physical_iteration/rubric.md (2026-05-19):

# T04 Evaluator Rubric

Use this to score the human-evaluation components of T04.

## Expected diagnoses and fixes

These are the correct answers. Do not share with agents before evaluation.

### Problem 1 — Pin cannot insert

**Root cause:** `PIN_CLEARANCE_MM` is 0.46 mm for the nominal pin in the current
PETG profile. FDM printers typically under-size holes by 0.1–0.2 mm due to
material expansion and elephant foot. The effective bore is smaller than designed.

**Correct fix:** Increase `PIN_CLEARANCE_MM` by 0.08–0.15 mm (e.g., 0.54–0.58 mm
for PETG) **or** direct the user to use the `pin_loose` variant (PIN_RADIUS_MM=1.02).
A config change to `PIN_CLEARANCE_MM` = 0.54 is the most direct solution.

**Acceptable alternative:** Add a new PETG-specific pin clearance value to
`MATERIAL_PROFILES` and document how to apply it.

**Not acceptable:** Suggesting to drill out the bore manually (not a design fix).

---

### Problem 2 — Teeth scrape on close

**Root cause:** `SLOT_CLEARANCE_MM` = 0.54 mm is insufficient for PETG stringing
and elephant-foot effects. The slot mouth (`SLOT_MOUTH_MM` = 0.82 mm) is nearly
the same as the tooth width (`TOOTH_WIDTH_MM` = 0.82 mm) — zero clearance at entry.

**Correct fix:** Increase `SLOT_CLEARANCE_MM` by 0.08–0.15 mm (e.g., 0.62–0.68 mm)
**and/or** increase `SLOT_MOUTH_MM` by 0.1–0.2 mm to widen the entry chamfer.

**Not acceptable:** Suggesting to file the teeth manually.

---

### Problem 3 — Hinge wobble after 20 cycles

**Root cause:** `HINGE_KNUCKLE_GAP_MM` = 0.48 mm. For PETG, this gap may be tight
enough to create initial friction and wear. A slightly larger gap (0.55–0.65 mm)
would reduce wear while still maintaining alignment.

**Correct fix:** Increase `HINGE_KNUCKLE_GAP_MM` to 0.55–0.65 mm.

**Note:** This is in tension with Problem 1 (more clearance = more wobble). The
agent should acknowledge this and choose a balanced value.

---

### Problem 4 — Hook does not latch reliably

**Root cause:** `HOOK_SWEEP_DEG` = 275° and `HOOK_INNER_R_MM` = 2.8 mm. A larger
sweep angle (285–300°) would curl the hook tip further inward, making it more
likely to catch. Alternatively, reducing `HOOK_INNER_R_MM` makes the hook curl
tighter.

**Correct fix:** Increase `HOOK_SWEEP_DEG` to 285–295° **or** decrease
`HOOK_INNER_R_MM` to 2.2–2.5 mm.

**Note:** Changing `HOOK_INNER_R_MM` also affects hook clearance — must regenerate
and verify arms don't collide.

---

## Scoring guidance for evaluators

Award full diagnosis points (12/problem) if the agent:
- Identifies the correct config parameter
- Gives a direction of change (increase/decrease) that is correct
- Gives a magnitude that is physically reasonable

Award partial diagnosis points (6/problem) if the agent:
- Identifies the right general area (e.g., "pin clearance") but not the exact parameter
- Gets the direction right but the magnitude unreasonably large or small

Award 0 diagnosis points if the agent:
- Blames the printer (not the design)
- Recommends post-print manual fixes without any design change
- Identifies the wrong parameter

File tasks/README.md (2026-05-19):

# Benchmark Tasks

This directory contains five tasks of increasing difficulty for evaluating agentic AI
capability on a real engineering design problem. The goal in every task is the same:
produce printable, functional STL files for a banana hair clip that meets `SPEC.md`.

## Setup

```bash
git clone https://github.com/zhiqitao/3d-banana-hair-clip
cd 3d-banana-hair-clip
python -m venv .venv
source .venv/bin/activate   # Windows: .venv\Scripts\activate
pip install -r requirements.txt

# Verify the baseline passes before starting any task
python eval/check_spec.py
```

Expected output: `Automated criteria: 28/28 passed`.

## How to run a task

1. **Reset to baseline** before each task — tasks modify the repo:
   ```bash
   git stash        # or: git checkout -- .
   ```
2. Give the agent the task's `prompt.md` as its instructions and the full repo as context.
3. After the agent finishes, run the grader:
   ```bash
   python tasks/T02_resize/grader.py   # example for T02
   python eval/check_spec.py           # always run this too
   ```
4. Score human criteria (where applicable) using the task's `rubric.md`.

**Important:** Each task should start from the unmodified repo. Use a fresh clone or
`git stash` / `git checkout -- .` between tasks. The graders assume baseline config
values as the pre-task state.

The agent may read any file and run any script. The agent must not delete
`eval/baseline.json` or the `lesson/` directory.

## Task overview

| Task | Difficulty | Type | Automated grader |
|---|---|---|---|
| [T01 Spec Audit](T01_audit/prompt.md) | 1 / 5 | Comprehension — no code changes | No |
| [T02 Resize](T02_resize/prompt.md) | 2 / 5 | Single-parameter change | Yes |
| [T03 Tooth Density](T03_tooth_density/prompt.md) | 3 / 5 | Multi-constraint parameter change | Yes |
| [T04 Physical Iteration](T04_physical_iteration/prompt.md) | 4 / 5 | Interpret failure report, diagnose, fix | Partial |
| [T05 Design Extension](T05_design_extension/prompt.md) | 5 / 5 | New geometry feature in generator code | Partial |

## Scoring framework

Each task is scored out of 100 using a task-specific rubric. Scores roll up to a
benchmark score:

| Component | Weight |
|---|---|
| T01 Spec Audit | 10% |
| T02 Resize | 15% |
| T03 Tooth Density | 20% |
| T04 Physical Iteration | 25% |
| T05 Design Extension | 30% |

## What this benchmark tests

| Capability | Where it appears |
|---|---|
| Code reading and comprehension | T01, T02 |
| Parametric design reasoning | T02, T03 |
| Multi-constraint satisfaction | T03, T04 |
| Physical / manufacturing intuition | T04, T05 |
| Code modification and geometry generation | T05 |
| Validation discipline (run scripts, don't just claim success) | All tasks |

## Ground rules for agents

- Success must be proven by running scripts. Code appearance is not enough.
- Do not claim that STL files were regenerated unless `outputs_fit_demo/` timestamps changed.
- Run `python eval/check_spec.py` after any geometry change.
- If a check fails, diagnose and fix — do not skip the check.

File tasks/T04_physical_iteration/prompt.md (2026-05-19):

# T04 — Physical Iteration from Print Failure

**Difficulty:** 4 / 5
**Type:** Diagnose a real failure report, propose fixes, implement, validate
**Time budget:** 60 minutes

---

## Context

A first print was completed. The clip assembles but has four problems that make it
unusable as a daily hair clip. The full failure report is in `failure_report.md`
in this directory.

---

## Your task

Read `failure_report.md` carefully. For each reported problem:

1. **Diagnose** — identify the root cause in the codebase (file and parameter/line)
2. **Propose** — state the specific change you will make and why
3. **Implement** — make the change in `scripts/config.py` or the generator script
4. **Validate** — run `python eval/check_spec.py` and confirm the change does not
   break any automated criteria

You must address all four reported problems. If fixing one problem conflicts with
fixing another, explain the trade-off and resolve it.

---

## Constraints

- Do not change `TOOTH_COUNT` (leave it at the current value)
- Do not change `ARM_LENGTH_MM` (leave it at the current value)
- All S1 geometry checks must still pass after your changes
- At least two of the four problems must be addressed with a parameter change in
  `scripts/config.py` (not just a comment or documentation change)

---

## What to deliver

A structured response with four sections — one per problem:

```
### Problem 1: [Name from failure report]
Diagnosis: [root cause — specific file, parameter, line]
Change: [exact parameter name and new value]
Rationale: [why this value]
```

Then: the full output of `python eval/check_spec.py` after all changes are applied.

---

## Automated grader

```bash
python eval/check_spec.py
```

All S1–S4 checks must still pass. No dedicated task grader — the spec checker
is the gate.

---

## Scoring rubric

| Criterion | Points |
|---|---|
| Problem 1 diagnosed correctly with code location | 12 |
| Problem 2 diagnosed correctly with code location | 12 |
| Problem 3 diagnosed correctly with code location | 12 |
| Problem 4 diagnosed correctly with code location | 12 |
| At least 2 fixes implemented in config.py | 15 |
| All S1–S4 spec checks still pass | 20 |
| Trade-off explanation if any fixes conflict | 10 |
| Check output quoted (not just claimed) | 7 |
| **Total** | **100** |

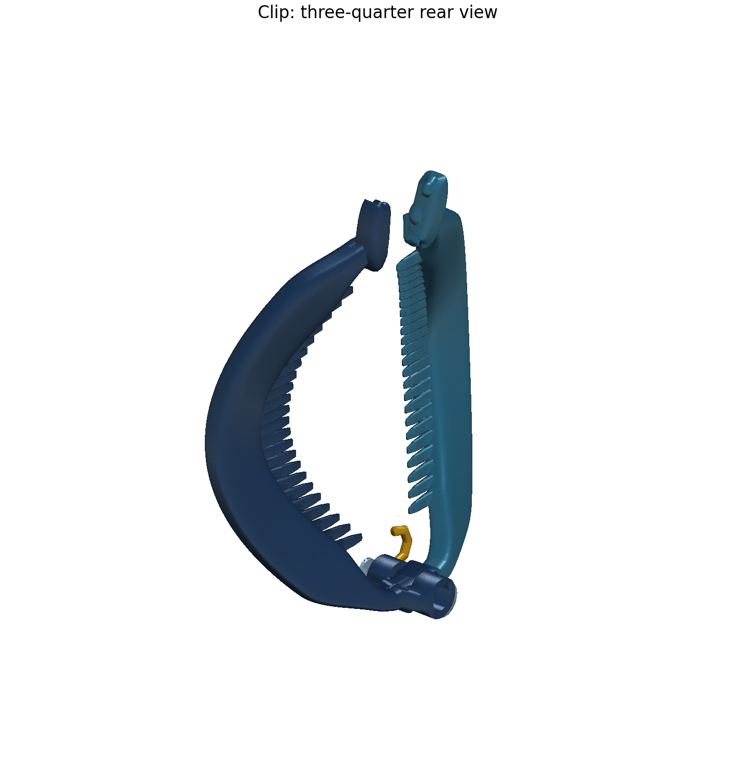
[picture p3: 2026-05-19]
assets/clip_three_quarter.png

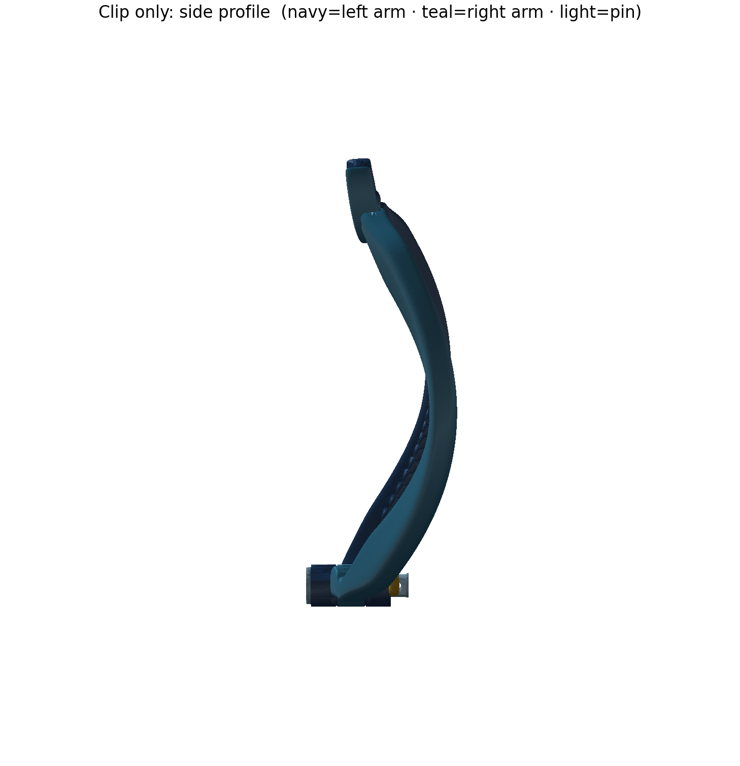
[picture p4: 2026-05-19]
assets/actual_clip_hinge_side.png

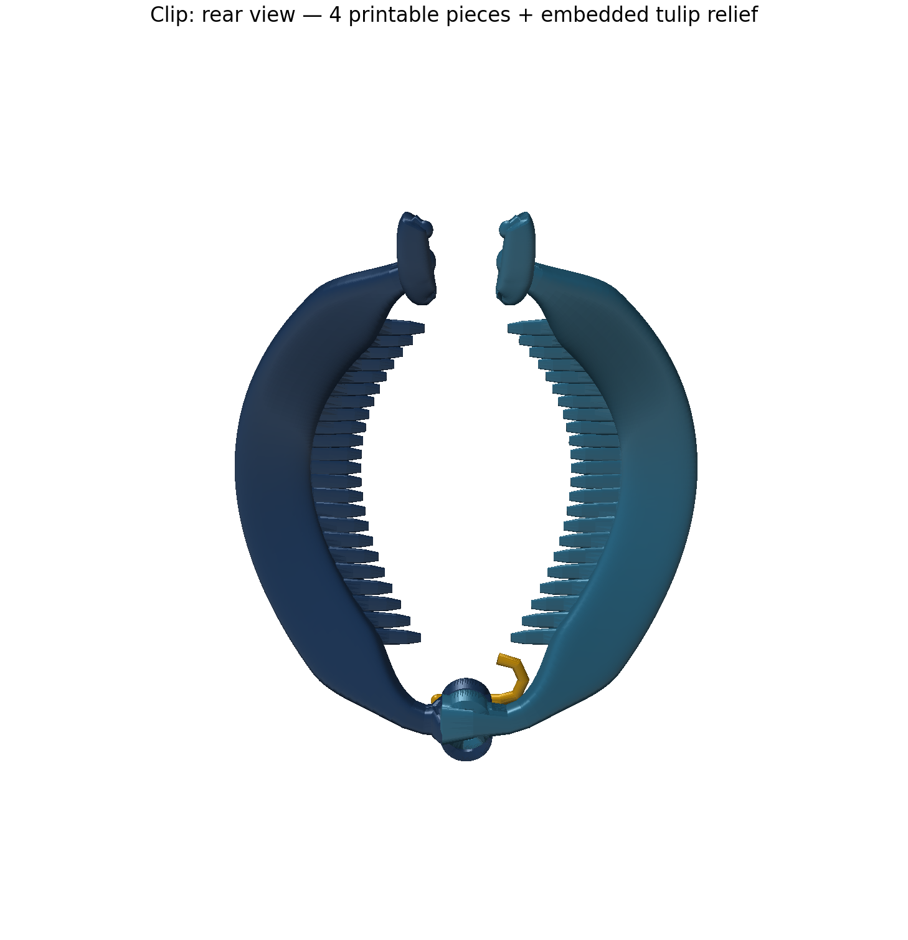
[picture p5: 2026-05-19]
assets/clip_rear_view.png

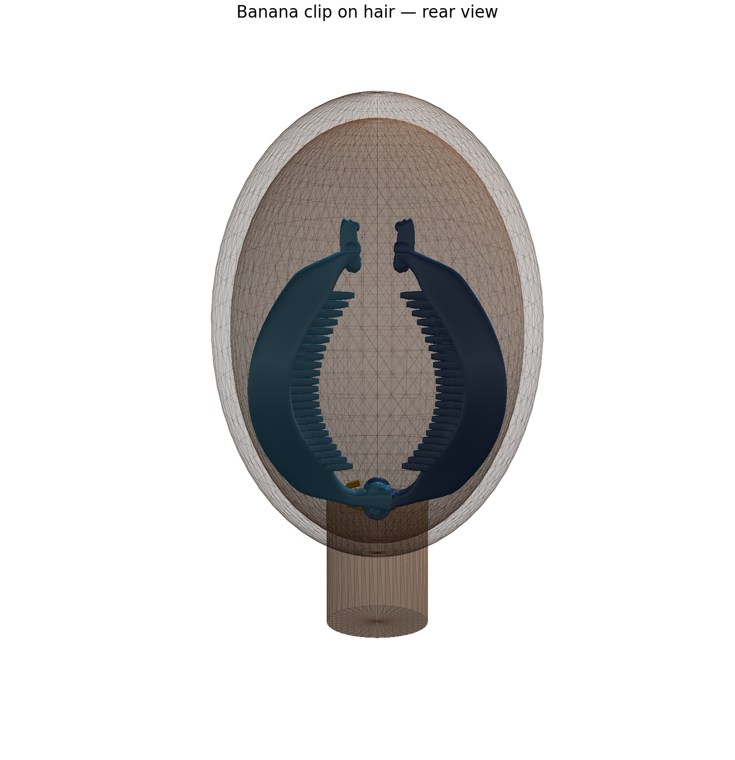
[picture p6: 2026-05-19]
assets/photo_refactored_fit_demo.png

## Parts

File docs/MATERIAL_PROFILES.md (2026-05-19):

# Material Profiles

The geometry defaults are conservative for a first demo. Material choice still matters.

## PLA first demo

Best for:

- clean first print
- easiest slicing
- low warping
- good dimensional accuracy

Weakness:

- brittle hinge and teeth
- poor long-term flex

Recommendation:

Use PLA for coupon plate and first visual prototype, not for the final functional clip.

## PETG functional prototype

Best for:

- better toughness than PLA
- more forgiving flex
- practical home printing

Weakness:

- stringing
- slightly worse dimensional crispness
- needs cleaner tuning

Recommendation:

Use PETG for the first serious functional banana clip.

## Nylon / PA advanced prototype

Best for:

- toughness
- flex
- durability

Weakness:

- moisture sensitivity
- harder print setup
- often needs drying and enclosure

Recommendation:

Use only after the geometry is proven in PLA/PETG.

## Why material profiles are not auto-applied

The repo documents material profiles instead of silently changing geometry because printer, slicer, nozzle, filament, humidity, and orientation all interact. Automatic material scaling without physical measurements can make the first print worse.

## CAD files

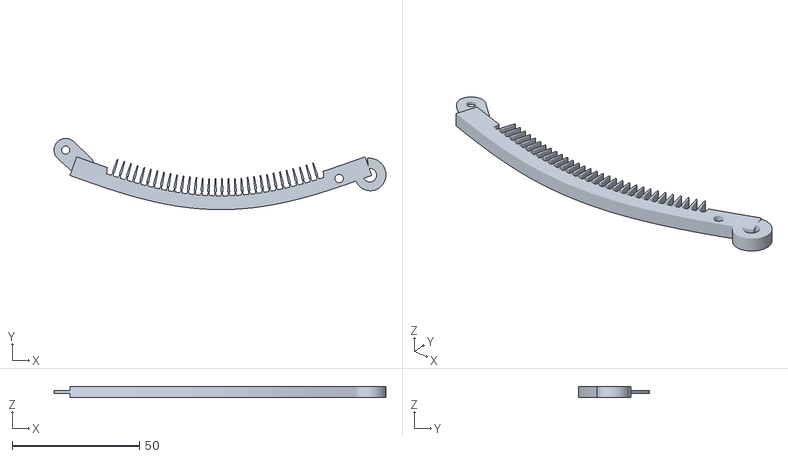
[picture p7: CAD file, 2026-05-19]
outputs_cad_stl/lower_arm.stl
130.5 x 28.0 x 4.50

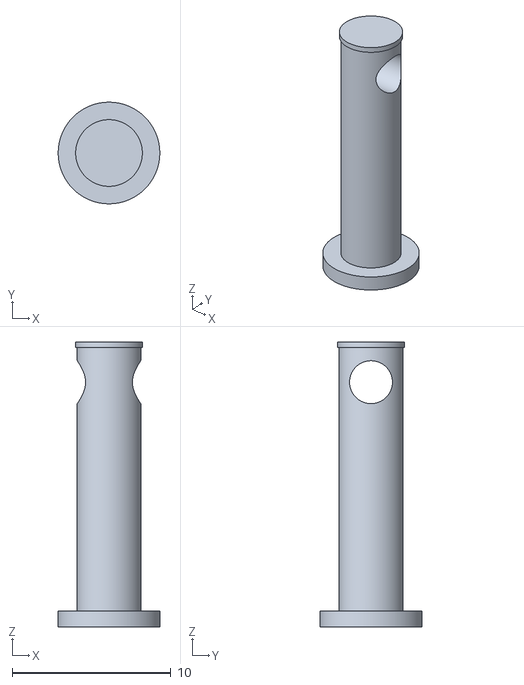
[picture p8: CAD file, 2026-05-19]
outputs_fit_demo/hinge_pin.stl
6.40 x 6.40 x 17.9

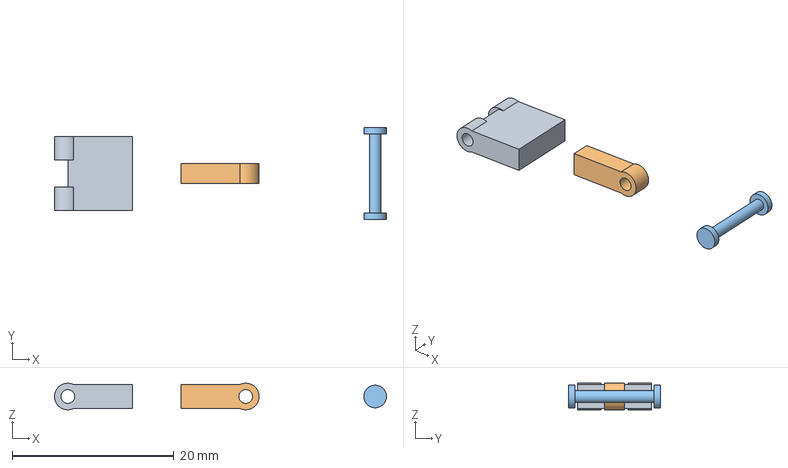
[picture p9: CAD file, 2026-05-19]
outputs_step/fb_hinge_coupon.step
41.0 x 11.4 x 3.29 mm

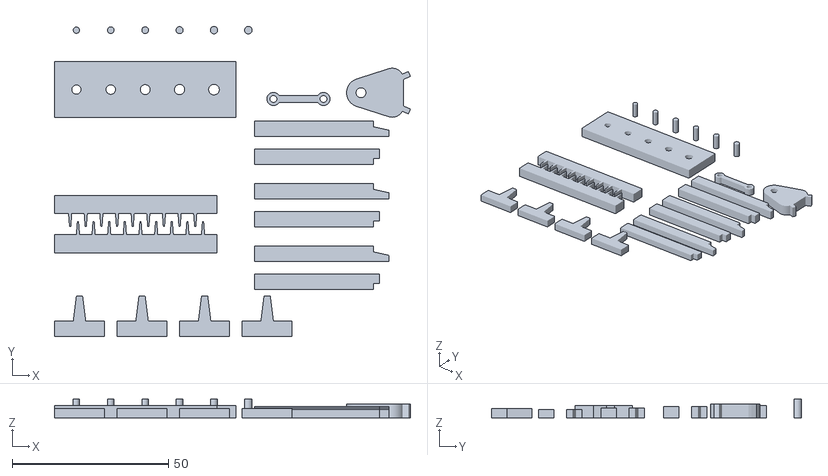
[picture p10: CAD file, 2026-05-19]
outputs_cad_stl/coupon_plate_first.stl
113.8 x 99.2 x 6.00

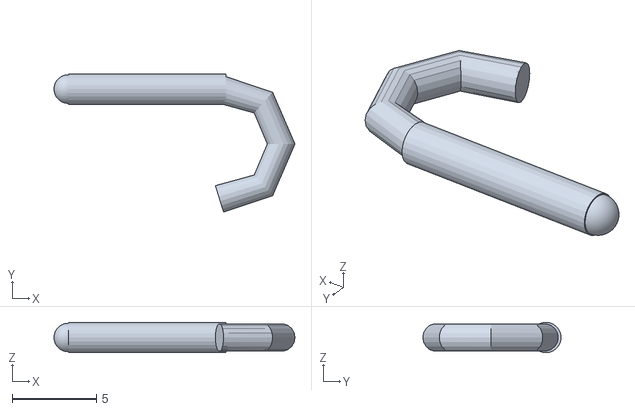
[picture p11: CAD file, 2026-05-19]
outputs_fit_demo/hinge_cotter.stl
14.3 x 8.18 x 1.80

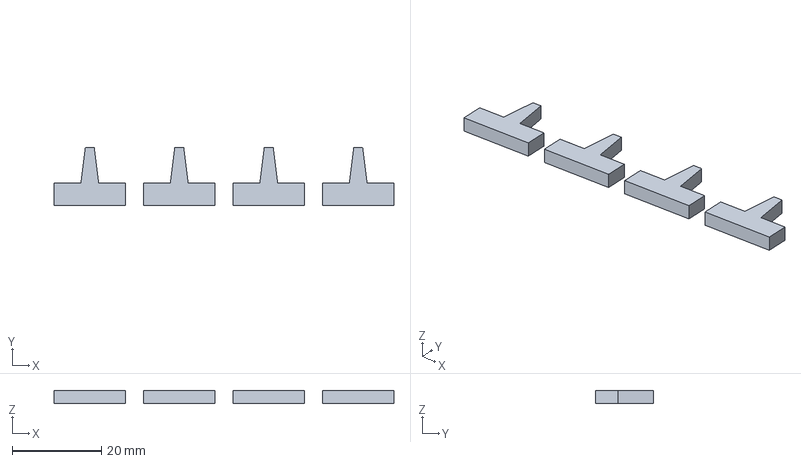
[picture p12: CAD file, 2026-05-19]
outputs_step/comfort_radius_coupon.step
76.0 x 13.0 x 3.00 mm

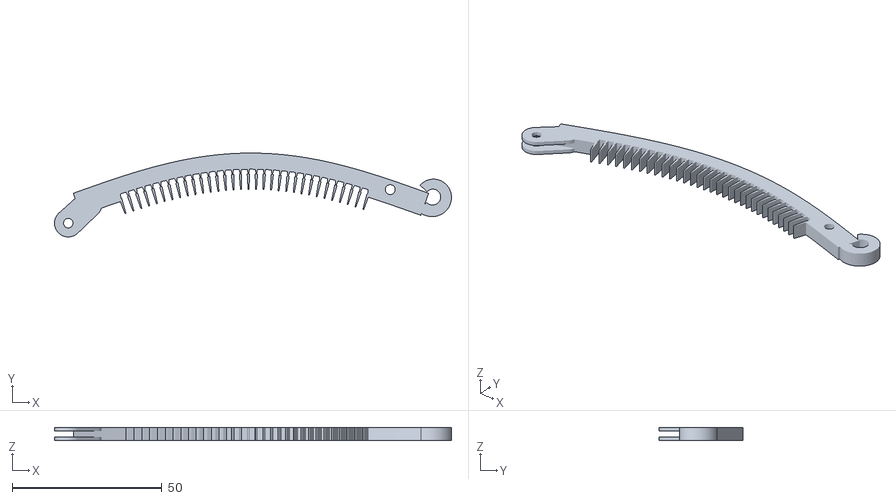
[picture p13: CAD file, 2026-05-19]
outputs_cad_stl/upper_arm.stl
132.6 x 28.0 x 4.50

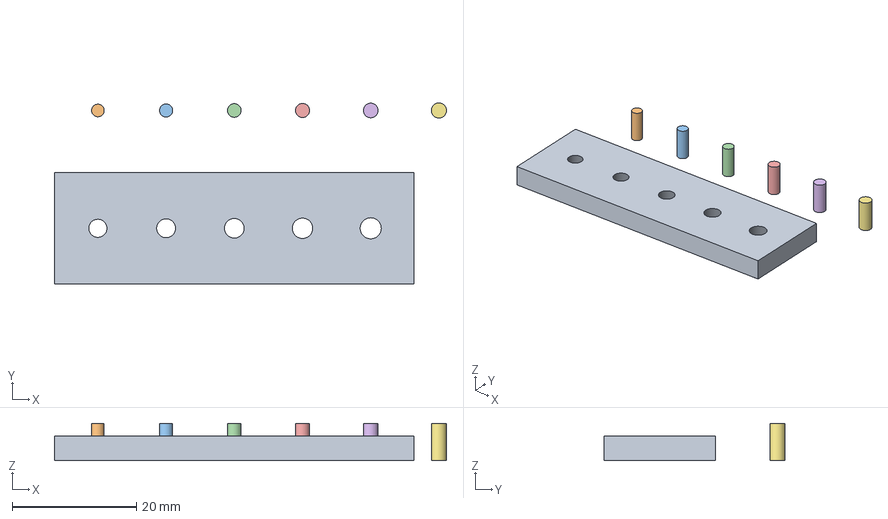
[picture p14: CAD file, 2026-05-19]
outputs_step/tolerance_kit.step
63.2 x 29.2 x 6.00 mm

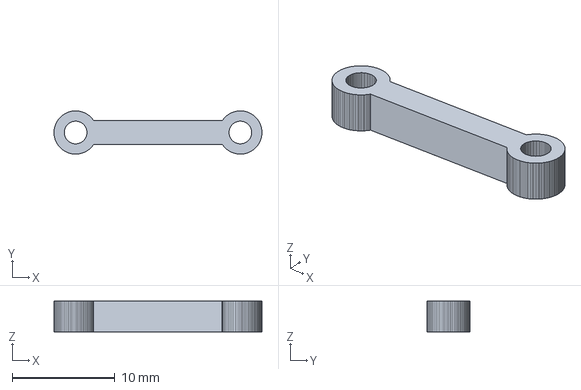
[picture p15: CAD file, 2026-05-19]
outputs_step/elastic_helper.step
20.2 x 4.20 x 3.00 mm

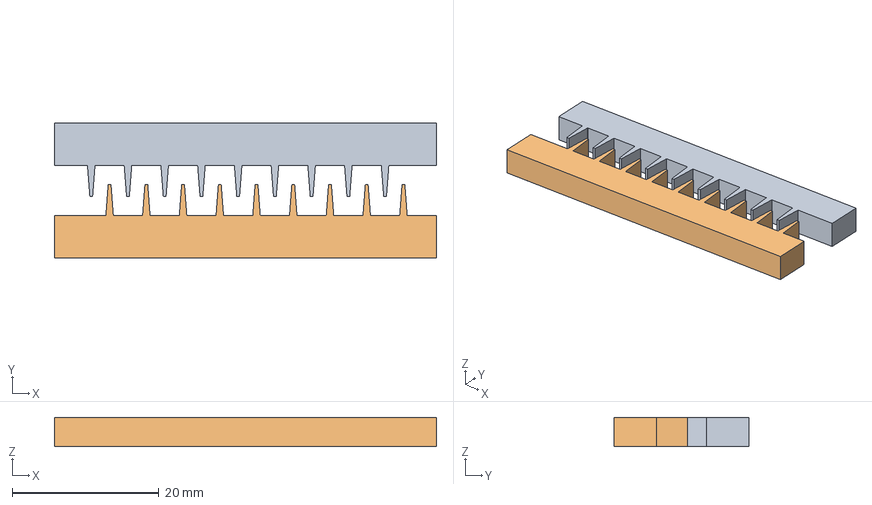
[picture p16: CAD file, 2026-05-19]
outputs_step/tooth_slot_coupon.step
52.0 x 18.4 x 4.00 mm

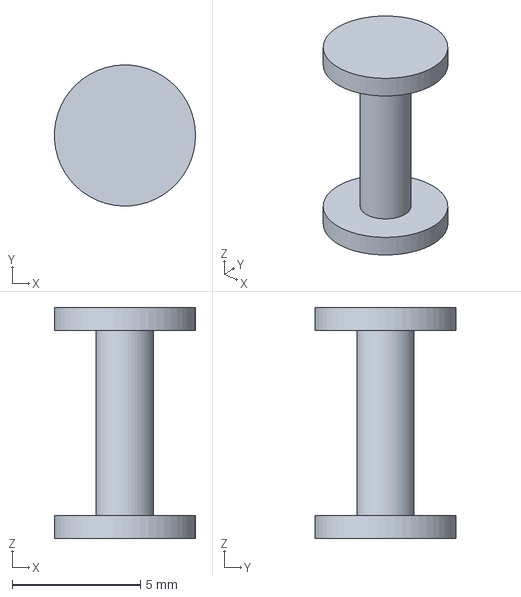
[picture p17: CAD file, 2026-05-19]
outputs_step/pin_nominal.step
5.49 x 5.50 x 9.00 mm

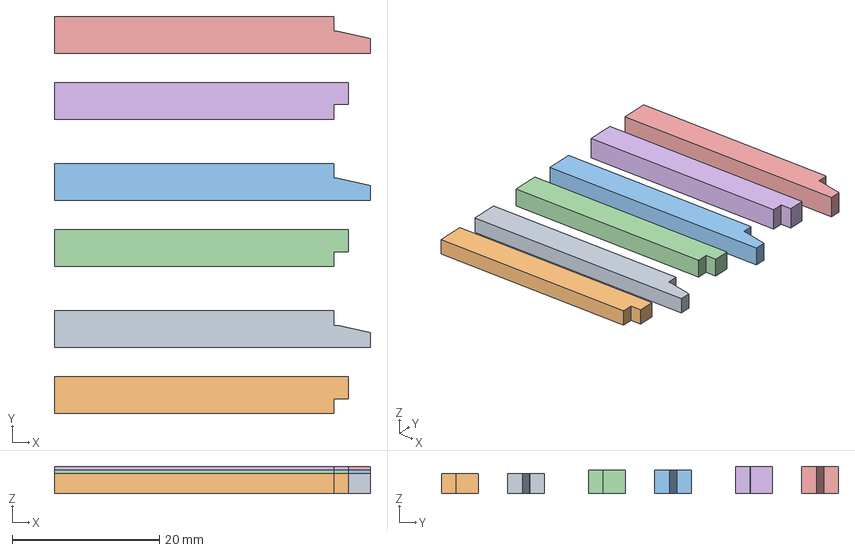
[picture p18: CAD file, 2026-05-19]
outputs_step/snap_latch_coupon.step
43.0 x 54.0 x 3.68 mm

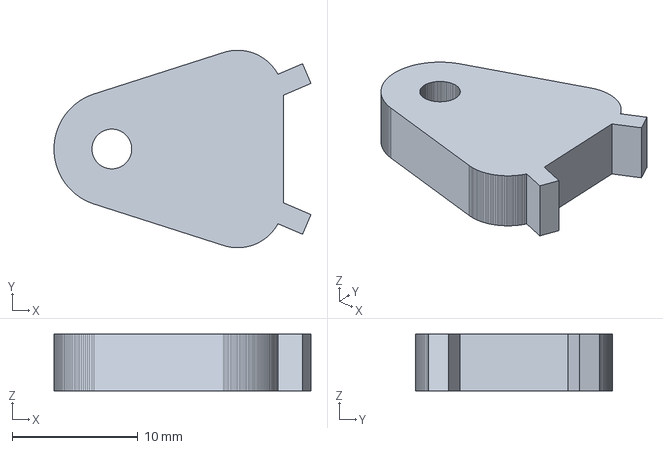
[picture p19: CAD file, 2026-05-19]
outputs_step/hinge_stress_coupon.step
20.4 x 15.7 x 4.50 mm

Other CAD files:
outputs_step/pin_loose.step
outputs_step/pin_snug.step
outputs_cad_stl/comfort_radius_coupon.stl
outputs_cad_stl/elastic_helper.stl
outputs_cad_stl/fb_hinge_coupon.stl
outputs_cad_stl/hinge_stress_coupon.stl
outputs_cad_stl/pin_loose.stl
outputs_cad_stl/pin_nominal.stl
outputs_cad_stl/pin_snug.stl
outputs_cad_stl/snap_latch_coupon.stl
outputs_cad_stl/tolerance_kit.stl
outputs_cad_stl/tooth_slot_coupon.stl

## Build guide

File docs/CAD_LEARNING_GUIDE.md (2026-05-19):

# Real-Life CAD Design Process Lesson

This project is designed as a hands-on CAD lesson, not just a hair clip.

## 1. Observe the real object

Questions to ask:

- Where is the hinge axis?
- Which parts need to rotate?
- Where do the teeth interleave?
- What prevents the clip from opening by itself?
- Which features are cosmetic, and which are structural?

## 2. Turn observation into requirements

Example requirements:

- Two arms must not overlap when closed.
- Teeth must grip hair but not collide with the other arm.
- Hinge pin must fit with clearance.
- Print must be possible on a normal FDM printer.
- The model must be adjustable with parameters.

## 3. Build a simple model first

The early versions looked good but had hidden problems:

- floating hinge barrels
- arm body overlap
- missing pin hole
- teeth colliding with the opposite arm

This is a normal engineering lesson: a pretty model is not automatically a working design.

## 4. Validate before printing

Run:

```bash
python scripts/validate_geometry.py
```

The validation is not a replacement for a real print, but it catches obvious mistakes.

## 5. Print small tests first

Print the tolerance kit and elastic helper first. This teaches that CAD dimensions are ideal, but printed dimensions are real.

## 6. Iterate after the first physical test

Measure:

- pin fit
- hinge smoothness
- tooth scraping
- closing force
- comfort in hand
- whether hair actually stays in place

Then change one parameter at a time.

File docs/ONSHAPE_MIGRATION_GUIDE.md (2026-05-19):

# Onshape Migration Guide

The current model is STL-first because this environment does not have a full CAD kernel. For Onshape, the clean path is to rebuild the design from the parameter logic, not to edit STL triangles.

## Practical path

1. Open `outputs/banana_clip_v8_final_profiles.svg` as a visual reference.
2. Recreate one arm centerline sketch in Onshape.
3. Offset the centerline to create the arm body.
4. Add tooth pattern with linear pattern along the arm.
5. Add receiving slots as a matching staggered pattern.
6. Add hinge boss using circles and tangent/convex-hull-like sketch lines.
7. Extrude the Z layers:
   - upper arm: lower knuckle, middle body, upper knuckle
   - lower arm: lower body, middle knuckle, upper body
8. Add pin hole using a remove-extrude through the hinge axis.
9. Add fillets/chamfers.
10. Export STEP and STL.

## Teaching point

This is exactly how real CAD often works: use a script prototype to discover geometry, then rebuild the final version in a parametric CAD system once the layout is understood.

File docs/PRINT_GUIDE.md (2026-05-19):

# Print Guide

## Suggested material

- PLA or PLA+ for the first educational print.
- PETG may be better for a slightly more flexible prototype.
- Do not start with brittle exotic filament.

## Suggested slicer settings

- Layer height: 0.16–0.20 mm
- Walls/perimeters: 3+
- Infill: 30–50%
- Supports: likely not needed for the flat parts if oriented as generated
- Brim: optional, useful if teeth curl upward at the edges

## Orientation

Print each arm flat. The hinge pin is printed vertically by default in this mesh export. If the pin is weak, reprint it lying down or use a small metal pin/dowel instead.

## Assembly

1. Clean stringing from teeth and slots.
2. Test pin variants using the tolerance kit.
3. Stack the upper/lower hinge knuckles.
4. Insert the loose pin first.
5. Add a small elastic loop through the rear holes or around the curled grips to provide closing force.

## Expected first-try issues

| Symptom | Likely cause | Fix |
|---|---|---|
| Pin too tight | Printer closes holes / elephant foot | Use loose pin, drill hole lightly, or increase `PIN_CLEARANCE_MM` |
| Teeth scrape | Over-extrusion or slot clearance too small | Increase `SLOT_CLEARANCE_MM` by 0.1–0.2 mm |
| Clip too weak | PLA too brittle / low infill | Use PETG, increase walls, increase arm thickness |
| Elastic does not hold | Elastic too loose | Shorter elastic or move hole position in config |

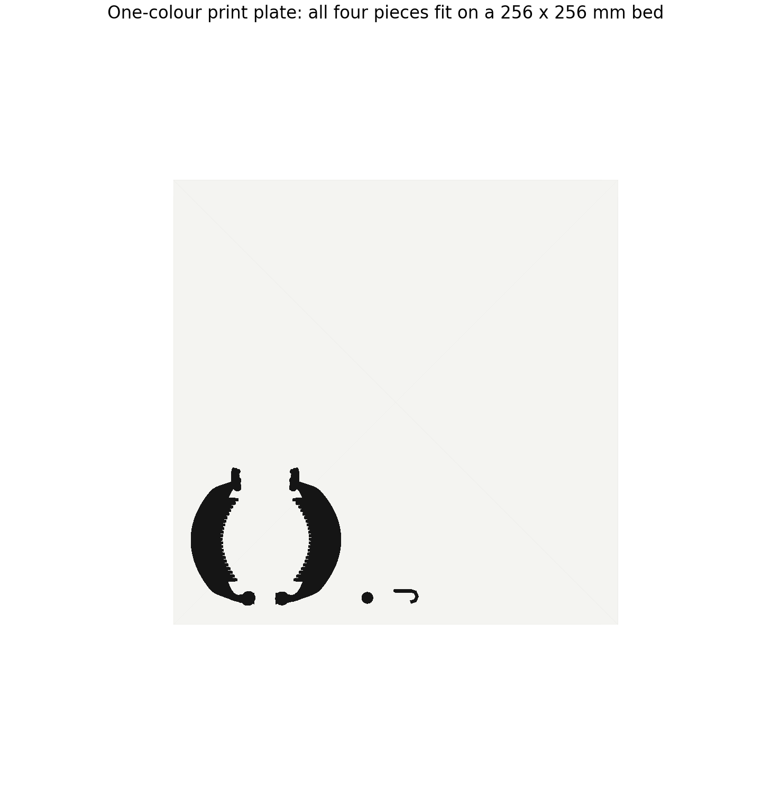
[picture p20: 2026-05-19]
assets/one_color_print_plate.png

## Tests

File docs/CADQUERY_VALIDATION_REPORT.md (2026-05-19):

# CadQuery Validation Report

This report is generated by `python cadquery/validate_cq.py`.

## Result

PASSED

## Checks

- `PASS outputs_step/upper_arm.step exists`
- `PASS outputs_cad_stl/upper_arm.stl exists`
- `PASS upper_arm.step non-empty STEP size=18968588`
- `PASS upper_arm.stl non-empty STL size=3471696`
- `PASS upper_arm.stl watertight CAD-derived STL`
- `PASS outputs_step/lower_arm.step exists`
- `PASS outputs_cad_stl/lower_arm.stl exists`
- `PASS lower_arm.step non-empty STEP size=17714670`
- `PASS lower_arm.stl non-empty STL size=3291552`
- `PASS lower_arm.stl watertight CAD-derived STL`
- `PASS outputs_step/pin_loose.step exists`
- `PASS outputs_cad_stl/pin_loose.stl exists`
- `PASS pin_loose.step non-empty STEP size=13642`
- `PASS pin_loose.stl non-empty STL size=326274`
- `PASS pin_loose.stl watertight CAD-derived STL`
- `PASS outputs_step/pin_nominal.step exists`
- `PASS outputs_cad_stl/pin_nominal.stl exists`
- `PASS pin_nominal.step non-empty STEP size=13642`
- `PASS pin_nominal.stl non-empty STL size=326557`
- `PASS pin_nominal.stl watertight CAD-derived STL`
- `PASS outputs_step/pin_snug.step exists`
- `PASS outputs_cad_stl/pin_snug.stl exists`
- `PASS pin_snug.step non-empty STEP size=13634`
- `PASS pin_snug.stl non-empty STL size=326162`
- `PASS pin_snug.stl watertight CAD-derived STL`
- `PASS outputs_step/tolerance_kit.step exists`
- `PASS outputs_cad_stl/tolerance_kit.stl exists`
- `PASS tolerance_kit.step non-empty STEP size=2162674`
- `PASS tolerance_kit.stl non-empty STL size=991365`
- `PASS tolerance_kit.stl watertight CAD-derived STL`
- `PASS outputs_step/elastic_helper.step exists`
- `PASS outputs_cad_stl/elastic_helper.stl exists`
- `PASS elastic_helper.step non-empty STEP size=1211078`
- `PASS elastic_helper.stl non-empty STL size=242937`
- `PASS elastic_helper.stl watertight CAD-derived STL`
- `PASS outputs_step/hinge_stress_coupon.step exists`
- `PASS outputs_cad_stl/hinge_stress_coupon.stl exists`
- `PASS hinge_stress_coupon.step non-empty STEP size=993551`
- `PASS hinge_stress_coupon.stl non-empty STL size=202999`
- `PASS hinge_stress_coupon.stl watertight CAD-derived STL`
- `PASS outputs_step/tooth_slot_coupon.step exists`
- `PASS outputs_cad_stl/tooth_slot_coupon.stl exists`
- `PASS tooth_slot_coupon.step non-empty STEP size=511710`
- `PASS tooth_slot_coupon.stl non-empty STL size=103582`
- `PASS tooth_slot_coupon.stl watertight CAD-derived STL`
- `PASS outputs_step/snap_latch_coupon.step exists`
- `PASS outputs_cad_stl/snap_latch_coupon.stl exists`
- `PASS snap_latch_coupon.step non-empty STEP size=195508`
- `PASS snap_latch_coupon.stl non-empty STL size=32780`
- `PASS snap_latch_coupon.stl watertight CAD-derived STL`
- `PASS outputs_step/comfort_radius_coupon.step exists`
- `PASS outputs_cad_stl/comfort_radius_coupon.stl exists`
- `PASS comfort_radius_coupon.step non-empty STEP size=161330`
- `PASS comfort_radius_coupon.stl non-empty STL size=27914`
- `PASS comfort_radius_coupon.stl watertight CAD-derived STL`
- `PASS outputs_step/coupon_plate_first.step exists`
- `PASS outputs_cad_stl/coupon_plate_first.stl exists`
- `PASS coupon_plate_first.step non-empty STEP size=5062573`
- `PASS coupon_plate_first.stl non-empty STL size=1591809`
- `PASS coupon_plate_first.stl watertight CAD-derived STL`
- `PASS outputs_step/fb_hinge_coupon.step exists`
- `PASS outputs_cad_stl/fb_hinge_coupon.stl exists`
- `PASS fb_hinge_coupon.step non-empty STEP size=81744`
- `PASS fb_hinge_coupon.stl non-empty STL size=846539`
- `PASS fb_hinge_coupon.stl watertight CAD-derived STL`
- `PASS nominal pin clearance matches config: 0.460 mm`
- `PASS pin_loose radial clearance 0.560 mm`
- `PASS pin_nominal radial clearance 0.460 mm`
- `PASS pin_snug radial clearance 0.380 mm`
- `PASS upper slots clear lower teeth collision area 0.000000 mm^2`
- `PASS lower slots clear upper teeth collision area 0.000000 mm^2`
- `PASS full non-hinge opposing-arm overlap 0.000000 mm^2`
- `PASS upper layer 0.00-1.26 valid area=1004.42`
- `PASS upper layer 1.26-3.24 valid area=914.32`
- `PASS upper layer 3.24-4.50 valid area=1004.42`
- `PASS lower layer 0.00-1.74 valid area=903.74`
- `PASS lower layer 1.74-2.76 valid area=993.84`
- `PASS lower layer 2.76-4.50 valid area=903.74`
- `PASS hinge knuckle Z ranges interleaved upper 0.00-1.26 vs lower 1.74-2.76`
- `PASS hinge knuckle Z ranges interleaved upper 3.24-4.50 vs lower 1.74-2.76`
- `PASS upper hinge knuckle ranges present: [(0.0, 1.26), (3.24, 4.5)]`
- `PASS lower hinge knuckle ranges present: [(1.74, 2.76)]`

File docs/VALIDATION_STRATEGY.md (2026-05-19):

# Validation Strategy

## Software validation

The script checks what can be checked without a physical print:

- 2D arm body overlap
- tooth collision against slotted body
- full closed non-hinge overlap
- hinge boss contact area
- layer validity
- pin clearance
- STL watertightness

Run:

```bash
python scripts/banana_clip_design_final.py
python scripts/validate_geometry.py
```

## Coupon validation

The final package includes small coupons to reduce first-print risk:

| Coupon | Purpose |
|---|---|
| `tolerance_kit.stl` | pin/hole fit calibration |
| `elastic_helper.stl` | elastic/hair-band fit |
| `hinge_stress_coupon.stl` | hinge boss print quality and layer adhesion |
| `tooth_slot_coupon.stl` | tooth and slot geometry |
| `snap_latch_coupon.stl` | latch feel without risking full clip |
| `comfort_radius_coupon.stl` | tooth-tip comfort comparison |

## Physical validation

Physical validation should be treated as data collection, not pass/fail ego.

Record:

- material
- nozzle size
- layer height
- walls/perimeters
- infill
- orientation
- pin fit
- hinge motion
- tooth comfort
- closing force
- visible failure mode

Use `lesson/TEST_LOG_TEMPLATE.md`.

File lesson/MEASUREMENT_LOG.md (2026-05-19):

# Measurement Log

| Item | Target | Actual | Notes |
|---|---:|---:|---|
| Loose pin fit | easy rotation |  |  |
| Nominal pin fit | firm rotation |  |  |
| Snug pin fit | tight but usable |  |  |
| Elastic hole fit | elastic passes cleanly |  |  |
| Tooth slot clearance | no visible collision |  |  |
| Hinge wobble | low |  |  |
| Closing force | enough to hold hair |  |  |
| Tooth comfort | no sharp scratch |  |  |
| Visible warp | none/minor |  |  |

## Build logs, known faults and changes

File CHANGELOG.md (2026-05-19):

# Changelog

## Hook interlock + slimmer hinge comfort pass

- Smoothed the arm-to-hook transition with an added root fairing so the hook no
  longer stands off the arm like a separate lump.
- Added a small inward retaining beak at each hook tip so the two arms have a
  better chance of catching each other when clamped shut.
- Shortened the hinge Y-span and narrowed the cheek bridges to reduce the thick,
  overbuilt look around the hinge block.
- Moved the fixed pin head to the scalp side and reshaped it as a lower-profile
  round-edged head, while keeping the cotter hole and cotter retention on the
  outer side.
- Regenerated fit-demo STLs, renders, and the hinge simulation report. The
  updated printable parts remain watertight and the hinge sanity check still
  passes; slicer support/orientation review is still required for the arms.

## Smoother hook, hinge, and actual-STL preview

- Reworked the top hook curl with a smaller continuous path and a rounded
  high-resolution cap, so the latch end no longer presents as a chopped flat
  polygonal surface in slicer previews.
- Increased arm, tooth, hinge-bridge, hinge-barrel, and rounded-cap tessellation
  to reduce the faceted/cheap-looking STL surface in Bambu Studio.
- Replaced rectangular hinge anchor blocks with rounded swept cheek bridges,
  keeping the interleaved barrel hinge and real pin bore while making the hinge
  area less blocky against the head.
- Updated the render pipeline to use the fused printable STL pieces rather than
  pre-boolean construction shells, so demo images match what is loaded into
  Bambu Studio.
- Regenerated fit-demo STLs and preview renders. Validation confirms each
  individual printable STL is watertight and one connected component; slicer
  checks still recommend support/orientation review for the curved arms.

## Fused printable arm shells

- Fixed the Bambu Studio floating-shell problem by boolean-unioning each arm
  from its body, teeth, hinge leaves, hook, and tulip relief before STL export.
- Embedded tooth roots deeper into the arm body and rebuilt the top hooks so
  they overlap into the arm instead of sitting beside it.
- Added hinge cheek geometry so the barrel leaves are physically connected to
  the arm bodies while preserving the pin bore.
- Added `manifold3d` as the local mesh-union dependency for the fit-demo STL
  export path.
- Updated printability validation to report disconnected component count; each
  individual printable STL now reloads as one watertight component.
- Changed the four individual printable STL exports to be pre-oriented for
  Bambu Studio import. The assembled orientation is now kept only in the visual
  fit/demo STL outputs.

## Printable hinge bores + visible tulip face relief

- Replaced the visual-only hinge barrels in the fit-demo STL generator with
  hollow annular barrels, so both arms now have real pin bores.
- Rebuilt the hinge pin as a smooth clevis-style pin with a real transverse
  cotter hole near the outward flange.
- Replaced the decorative cotter concept with a straight printed cotter peg and
  pull loop that aligns with the hole through the pin.
- Moved the tulip decoration off the narrow spine edge and onto the broad flat
  arm face. The motif is now shallow filled tulip relief pads so Bambu Studio
  shows recognizable geometry instead of tiny diamond marks.
- Regenerated fit-demo STLs, preview renders, hinge simulation image/report,
  and the one-colour build-plate STL.
- Re-ran validation: all fit-demo printable STLs reload as watertight, hinge
  simulation passes, CadQuery STEP validation passes, and printability still
  warns that support/slicer review is required.

## Hinge comfort + wider embedded tulip relief

- Reduced the scalp-facing hinge pin protrusion by replacing the round inner
  head with a low-profile tip that stays close to the barrel face.
- Widened the hinge to a 16 mm Y-span and moved the larger retaining flange to
  the outward-facing side, keeping stability while moving bulk away from the
  head-contact side.
- Made the embedded tulip-vine relief slightly wider and more visible while
  keeping it shallow, connected, and same-colour for a molded-plastic look.
- Regenerated the fit-demo STLs and preview renders.
- Re-ran hinge simulation, per-piece watertight STL checks, and the no-slicer
  printability check. The geometry is watertight, but slicer review is still
  required because overhang/support warnings remain.

## Connected tulip relief + restored STEP workflow

- Replaced separate raised rose-bead decorations with a continuous tulip-vine
  relief embedded into each arm spine. Each side's decoration is now one
  watertight connected relief body instead of many isolated spheres.
- Rounded the fit-demo arm and tooth sweep sections so edges read more like
  molded plastic and less like sharp rectangular prototype bars.
- Made the tulip relief subtle and same-colour in renders, closer to an
  embedded pattern than stand-out flower buds.
- Regenerated the fit-demo STLs and renders, including a clearer top-down
  one-colour build-plate preview.
- Restored the design-final STL fallback generator required by the CadQuery
  workflow and regenerated `outputs_step/` plus matching `outputs_cad_stl/`
  files for Onshape/CAD handoff.
- Re-ran CadQuery validation: STEP files exist, are non-empty, and matching
  CAD-derived STLs are watertight.

## Robust barrel-knuckle hinge + cotter pin retention + repo cleanup

- Redesigned hinge from thin webs (1.5 mm dia, failure-prone) to a solid
  bridge block + three interleaved barrel cylinders (7 mm OD, 14 mm Y-span).
- Arm depth is now constant at 4.5 mm throughout — no taper at the hinge end,
  which would crack under PLA/PETG in daily use.
- Split hinge into four distinct printable pieces: left arm (outer barrels),
  right arm (inner barrel), pin, and cotter. Each piece rendered in a distinct
  colour in all preview images.
- Replaced dual symmetric pin caps (uninsertable) with a proper retention
  design: fixed head flange on entry side + printed U-shaped hairpin cotter
  through a transverse bore near the exit tip.
- Exported per-piece STLs: `arm_left.stl`, `arm_right.stl`, `hinge_pin.stl`,
  `hinge_cotter.stl` in `outputs_fit_demo/`.
- Removed obsolete generators (`banana_clip_design_final.py`,
  `banana_clip_v8_final.py`, `validate_geometry.py`), old output directories
  (`outputs/`, `outputs_cad_stl/`, `outputs_step/`), stale docs, and old
  render assets.
- Rewrote README to describe the four-piece print-and-assemble workflow.

## Fit-demo redesign: flat strip arms + clean pin hinge

- Rewrote `scripts/fit_demo_head_clip.py` arm geometry from round elliptical tubes to
  flat rectangular-section strips (11 mm wide face, 4.5 mm deep), matching the
  proportions of real banana clips in the reference photos.
- Replaced cylindrical post teeth attached to a ridge with direct cylindrical posts
  (r=1.35 mm, 10.5 mm long) projecting from the inner face of the flat strip,
  spaced ~6 mm — matching the dense-comb appearance in the reference photos.
- Replaced the exposed barrel-knuckle hinge with a minimal clean-plastic hinge:
  a small sphere at the pivot, Y-axis pin-head discs (the only visible hardware),
  and thin webs to each arm root.  No external knuckles or barrel hardware shown.
- Replaced the previous large wire hooks with proportional curled J-hooks (r≈2 mm)
  that taper and curl inward — matching the latch hooks in the reference photos.
- Removed the decorative inlay (the flat strip spine is already clean).
- Updated render color list to remove the inlay layer; all four renders regenerated.
- Hinge kinematic simulation still passes all checks.

## Front-back hinge coupon + additional renders

- Added `cadquery/banana_clip_cq.py: build_fb_hinge_coupon()` — a CadQuery B-rep
  solid with three printable pieces: outer knuckle (two Y-axis barrels), inner
  knuckle (one Y-axis barrel), and a test pin. Dimensions match the kinematically
  validated front-back hinge in `scripts/fit_demo_head_clip.py` (barrel_r=1.65,
  bore_r=0.85, pin_r=0.72, clearance=0.40). All three pieces export as one watertight
  STEP and STL for print testing before modifying the main arm geometry.
- Added `fb_hinge_coupon` to `cadquery/config_cq.py COUPON_PARTS`, so
  `cadquery/validate_cq.py` checks the STEP and STL automatically.
- Added two new clip-only renders to `scripts/fit_demo_head_clip.py`:
  `assets/clip_rear_view.png` (looking at the outer spine face) and
  `assets/clip_three_quarter.png` (diagonal back view), both with auto-fit framing.
- All 70 CadQuery validation checks pass; hinge simulation still passes.

## Curved-arm normal tooth correction

- Corrected tooth orientation so teeth grow along each curved arm's local inward normal instead of a global up/down direction.
- Updated receiving slots to follow the matching local arm tangent/normal frame.
- Regenerated mesh fallback outputs, CAD STEP files, CAD-derived STLs, previews, and validation reports.
- Changed CAD-derived STL export to high-precision ASCII tessellation from the OpenCascade solid so validation reloads remain watertight after the normal-following geometry change.

## True CAD-kernel CadQuery version

- Added `cadquery/banana_clip_cq.py` to generate OpenCascade B-rep solids.
- Added explicit CadQuery workflow files: `config_cq.py`, `export_all.py`, and `validate_cq.py`.
- Added STEP exports under `outputs_step/` and matching CAD-derived STL exports under `outputs_cad_stl/`.
- Preserved the design-final profile math while keeping the STL-first generator as a fallback.
- Added CadQuery tests for generated files, non-empty STEP files, watertight STL exports, pin clearance, and tooth/slot 2D collision checks.
- Added `docs/CADQUERY_VALIDATION_REPORT.md` generation.
- Added `docs/TRUE_CAD_KERNEL_VERSION.md` with STL-vs-STEP notes, Onshape import guidance, and physical validation boundaries.

## Design-Phase Final

- Added `scripts/banana_clip_design_final.py` as the final design-phase generator.
- Added softened tooth-tip geometry via `TOOTH_EDGE_RADIUS_MM`.
- Added first-impression coupon plate: `coupon_plate_first.stl`.
- Added new engineering coupons:
  - `hinge_stress_coupon.stl`
  - `tooth_slot_coupon.stl`
  - `snap_latch_coupon.stl`
  - `comfort_radius_coupon.stl`
- Added material profile guidance in `scripts/config.py`.
- Added GitHub Actions geometry validation workflow.
- Added final design-phase docs:
  - `docs/DESIGN_PHASE_FINAL_REVIEW.md`
  - `docs/FIRST_IMPRESSION_DEMO_PLAN.md`
  - `docs/MATERIAL_PROFILES.md`
  - `docs/FAILURE_MODES_AND_EFFECTS.md`
  - `docs/VALIDATION_STRATEGY.md`
  - `docs/SNAP_LATCH_DECISION.md`
- Updated README to describe the final design workflow.

## Final v8 annotated package

- Added detailed engineering iteration history from v3 through Final v8.
- Added debug log covering arm overlap, floating hinge barrels, pin clearance, tooth collision, tolerance uncertainty, and STL editability limits.
- Added design-decision document explaining major tradeoffs.
- Added version-by-version review notes for teaching and future revision.
- Added engineering notebook with next physical test plan and likely first failures.

## Final v8

- Rebuilt arm export as layered Z-band profiles instead of same-part overlapping hinge solids.
- Increased tooth root embedding so teeth are structurally connected to the arm body.
- Preserved long tapered teeth and receiving slots.
- Added elastic helper test coupon.
- Added all-parts print plate as a convenience preview/plate file.
- Expanded validation and teaching documents.

## v7 baseline

- Added tolerance kit and pin variants.
- Added print guide and CAD migration docs.

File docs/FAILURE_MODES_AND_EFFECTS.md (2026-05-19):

# Failure Modes and Effects Review

| Failure mode | Likely cause | Design-phase mitigation | Physical-test action |
|---|---|---|---|
| Pin too tight | Hole shrinkage, elephant foot, slicer compensation | Three pin sizes + tolerance kit | Start with loose pin; sand or reprint pin |
| Pin too loose | Oversized hole or undersized pin | Nominal and snug pins included | Try snug pin or reduce clearance |
| Hinge snaps | Layer orientation, brittle material, thin web | Larger hinge boss + hinge stress coupon | Print in PETG; increase boss radius |
| Teeth break | Teeth too thin, wrong material, layer direction | Tapered teeth + softened edges | Increase tooth width/root inset |
| Teeth scratch | Sharp tips or edges | Tooth edge rounding + comfort coupon | Increase `TOOTH_EDGE_RADIUS_MM` |
| Clip does not hold hair | Weak closing force | Elastic retention holes | Stronger/smaller elastic; later integrate latch |
| Snap latch fails | Material sensitivity | Snap latch coupon kept separate | Tune latch geometry after coupon test |
| Arms collide when closing | Bad gap/slot math | Validation checks body and tooth collisions | Increase gap or slot clearance |
| Slots print poorly | Slots too narrow or stringing | Oversized slot clearance | Reduce speed, tune retraction, or widen slots |
| Model looks toy-like | Lack of polish or explanation | Preview assets + docs + Git history | Present as engineering kit, not just object |

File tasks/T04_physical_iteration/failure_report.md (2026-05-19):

# Print Failure Report

**Printer:** Bambu Lab P1S
**Material:** PETG, generic brand
**Nozzle:** 0.4 mm hardened steel
**Layer height:** 0.20 mm
**Walls:** 3
**Infill:** 40% gyroid
**Bed temp:** 70°C, nozzle 240°C
**Orientation:** Arms flat (spine down), pin upright, cotter flat

---

## Problem 1 — Pin cannot be inserted

The nominal pin (`hinge_pin.stl`) cannot be inserted into the hinge barrels by hand.
Significant force with a mallet was needed, and even then the pin only went halfway.
The pin tip is visibly bulging the barrel walls.

**Measurement:** Barrel bore measured with digital caliper: 3.72 mm.
Pin outside diameter measured: 3.84 mm.
Interference: ~0.12 mm, making hand insertion impossible.

**Impact:** The clip is currently non-functional. The loose pin variant was substituted
and inserts with moderate thumb pressure, but wobbles noticeably.

---

## Problem 2 — Teeth scrape against opposite arm on close

When the arms are brought together, the teeth on the left arm scrape audibly against
the right arm body (not the slots). The teeth are catching on the slot-side face
rather than dropping cleanly into the slots.

**Observation:** The scrape is worst in the first 5 mm of closing travel. After
forcing past it, the arms close but the scraping leaves visible scratch marks.

**Measurement:** Slot mouth measured at 0.71 mm. Tooth width measured at 0.84 mm.
The tooth root is slightly wider than the slot mouth.

**Impact:** Cannot close the clip smoothly. Fine PETG stringing inside slots may
be making this worse, but the root clearance geometry appears insufficient.

---

## Problem 3 — Hinge wobbles after 20 cycles

After approximately 20 open/close cycles, the hinge developed lateral play of
roughly 1 mm when the arms are loaded sideways. The cotter and pin are still in
place and intact.

**Observation:** The barrel axial gap appears to have worn. Under light finger
pressure, the left arm shifts ~1 mm in the Y-direction relative to the right arm.

**Hypothesis:** The knuckle gap between barrel faces was tight enough to bind
initially, causing micro-wear. The barrels are now too loose for a stable hinge.

**Impact:** The clip still opens and closes, but the lateral wobble is noticeable
during wear and makes the clip feel cheap.

---

## Problem 4 — Hook ends do not catch reliably

The hook at the tip of each arm is intended to interlock with the opposite arm's
hook when closed, providing a positive closing latch.

In practice, the hooks slide past each other roughly 40% of the time, requiring
a deliberate squeeze-and-twist motion to engage them. The clip will not stay
closed under the elastic tension of a hair bun without the hooks engaged.

**Observation:** The hook sweep angle appears too shallow — the hook tip does not
curl far enough inward to catch the opposite arm.

**Measurement:** The hook opens outward at the tip instead of pointing inward.
The hook inner radius appears larger than expected.

---

## Summary table

| # | Problem | Severity | Currently printable? |
|---|---|---|---|
| 1 | Pin cannot insert | Critical | No (substituted loose pin) |
| 2 | Teeth scrape on close | High | Functional but damaged |
| 3 | Hinge wobble after 20 cycles | Medium | Functional but poor feel |
| 4 | Hook does not latch reliably | High | Functional with care |
